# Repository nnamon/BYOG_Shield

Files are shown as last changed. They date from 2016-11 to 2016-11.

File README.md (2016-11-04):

# BYOG_Shield
Resources pertaining to the Build Your Own Arduino Shield workshop conducted by [AIS Cube](http://www.aiscube.com) and organised with [12Geeks](https://12geeks.com)

>Follow us on [Facebook](https://www.facebook.com/aiscube.sg)/[Instagram](https://www.instagram.com/aiscube.sg)/[Twitter](https://twitter.com/AIS_Cube) for upcoming public workshops & photos of those we conducted.

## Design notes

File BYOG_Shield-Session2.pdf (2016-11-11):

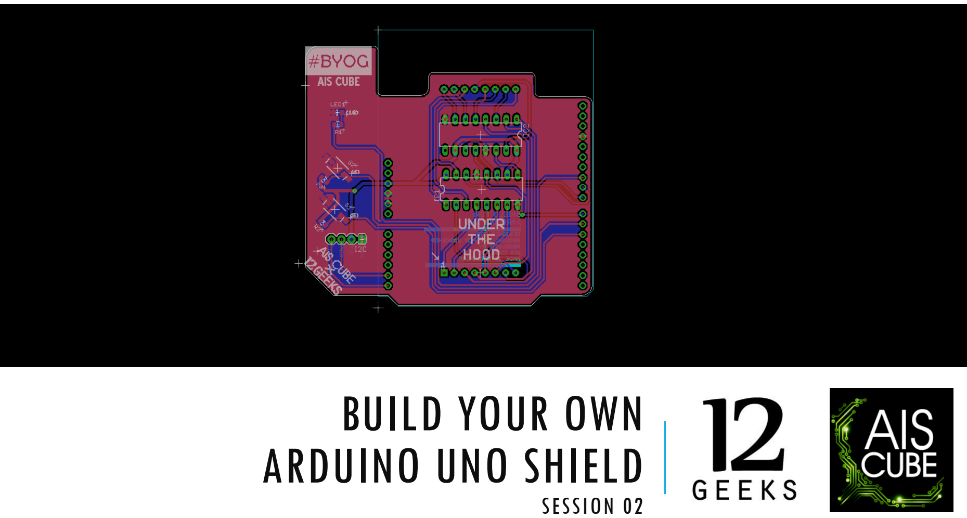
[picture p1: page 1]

# BUILD YOUR OWN ARDUINO UNO SHIELD

## SESSION 02

# LAST WEEK

Schematic
Drawing

Preparing
the board

Part
Placement

Preparing
to Route

Power
Lines

Signal
Lines

GND
Planes

Silkscreen
Items

## You learnt to:

- Breadboard & connect modules to the Arduino Uno
- Basic program to control the LEDs on the dot matrix
- Set up EAGLE directories
- Add components in EAGLE

# THIS WEEK

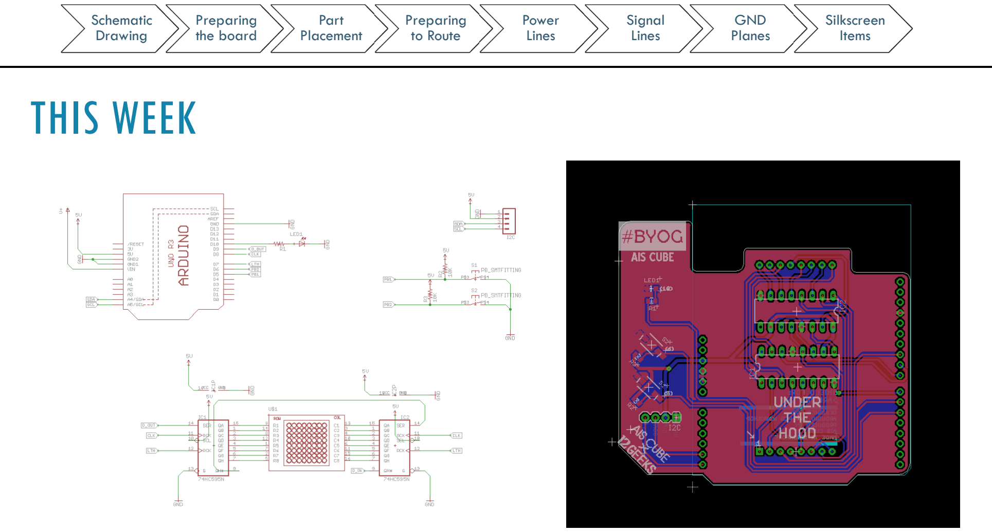
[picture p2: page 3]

Schematic
Drawing

Preparing
the board

Part
Placement

Preparing
to Route

Power
Lines

Signal
Lines

GND
Planes

Silkscreen
Items

# WAYPOINTS

- Board
Dimensions
- Change grid
units to mm
- Good parts
placement is
half the battle
won
- Change grid
units to 10 mil
- Setting up
route
parameters
- Eg. (Bend
Style, Width,
Via shape, via
drill size)
- Trace width
of 32 mil
- Route lines in
parallel on
bottom layer
- Trace width
of 16 mil
- Route lines on
top layer
- Polygons,
signals
and
ratsnest
- Logo
- Labels

# ADDING COMPONENTS

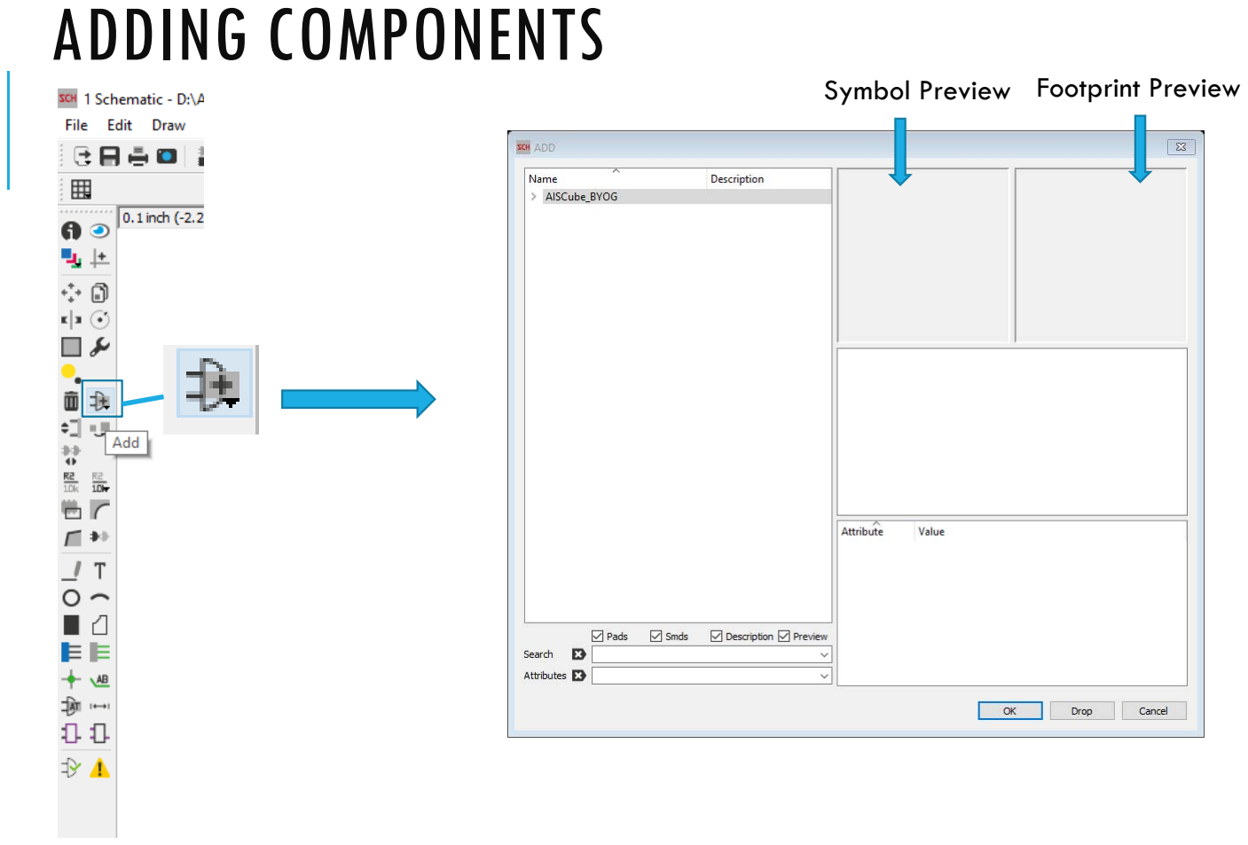
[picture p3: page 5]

Symbol Preview Footprint Preview

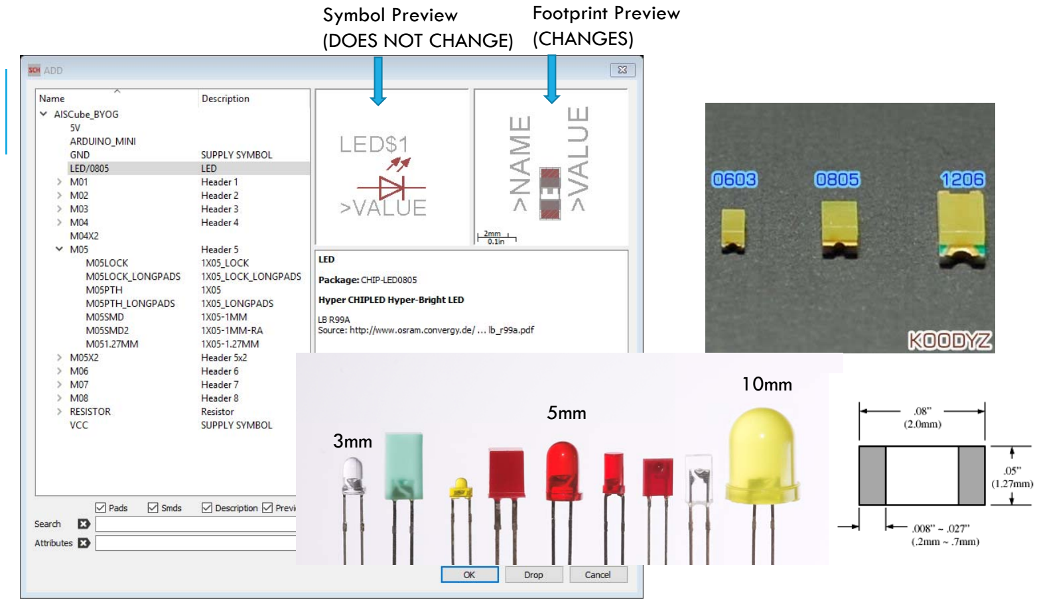
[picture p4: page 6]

Symbol Preview
(DOES NOT CHANGE)

Footprint Preview
(CHANGES)

3mm

5mm

10mm

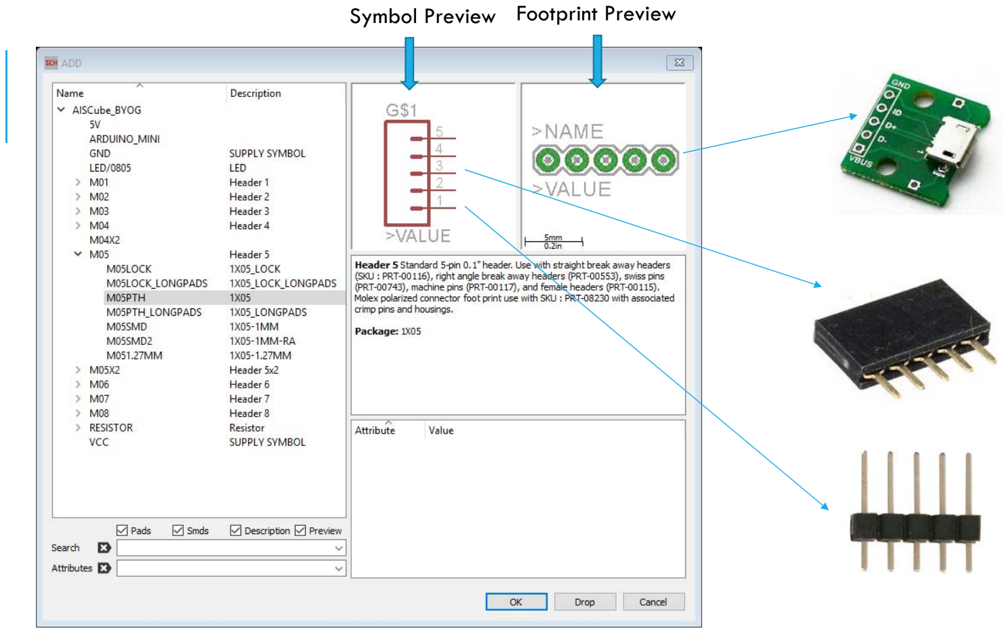
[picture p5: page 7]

Symbol Preview Footprint Preview

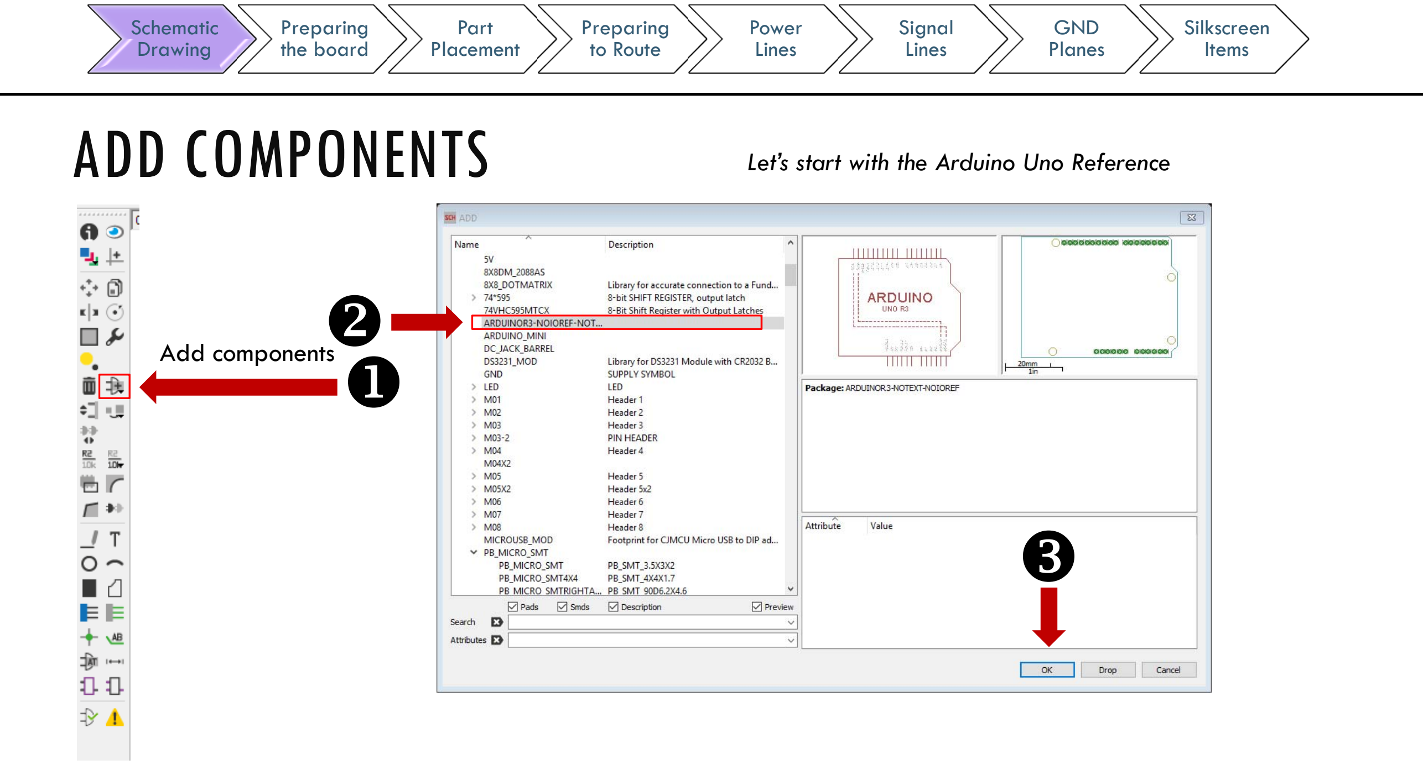
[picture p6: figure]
ADD COMPONENTS; Add components; Schematic Drawing; Preparing the board; Part Placement; Preparing to Route; Power Lines; Signal Lines; GND Planes; Silkscreen Items

Let’s start with the Arduino Uno Reference

# ADD POWER SYMBOLS

Add components

Schematic
Drawing

Preparing
the board

Part
Placement

Preparing
to Route

Power
Lines

Signal
Lines

GND
Planes

Silkscreen
Items

Add 5V and GND

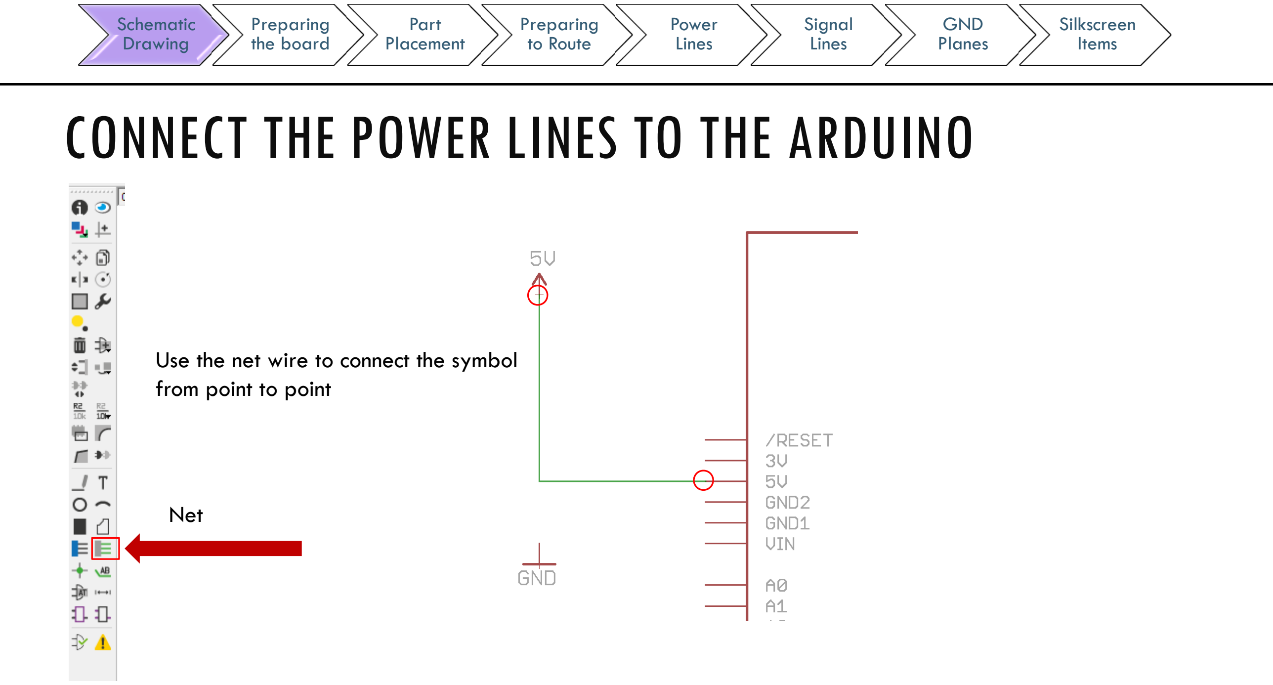
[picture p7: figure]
CONNECT THE POWER LINES TO THE ARDUINO; Net; Schematic Drawing; Preparing the board; Part Placement; Preparing to Route; Power Lines; Signal Lines; GND Planes; Silkscreen Items; Use the net wire to connect the symbol from point to point

# YOUR FIRST EAGLE CIRCUIT

Schematic
Drawing

Preparing
the board

Part
Placement

Preparing
to Route

Power
Lines

Signal
Lines

GND
Planes

Silkscreen
Items

# TRY DOING THIS BY YOURSELF

“Hello World” EAGLE style

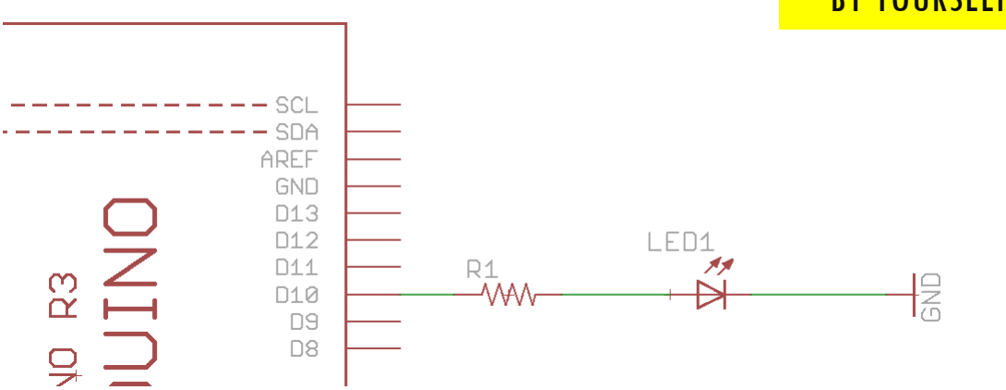
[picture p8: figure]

# UNDERSTANDING HOW .SCH & .BRD ARE CONNECTED

Schematic
Drawing

Preparing
the board

Part
Placement

Preparing
to Route

Power
Lines

Signal
Lines

GND
Planes

Silkscreen
Items

# EAGLE WALKTHROUGH

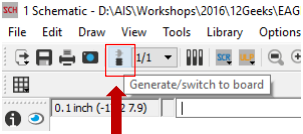
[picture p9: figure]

LIVE DEMO TIP :
Using move to auto-magically generate net wire connections.
Using copy to make copies of existing components (eg. GND) to add to the circuit. Net wire in .sch

→ air wire in .brd

# LET’S TRY THAT OUT WITH THE PUSH BUTTONS

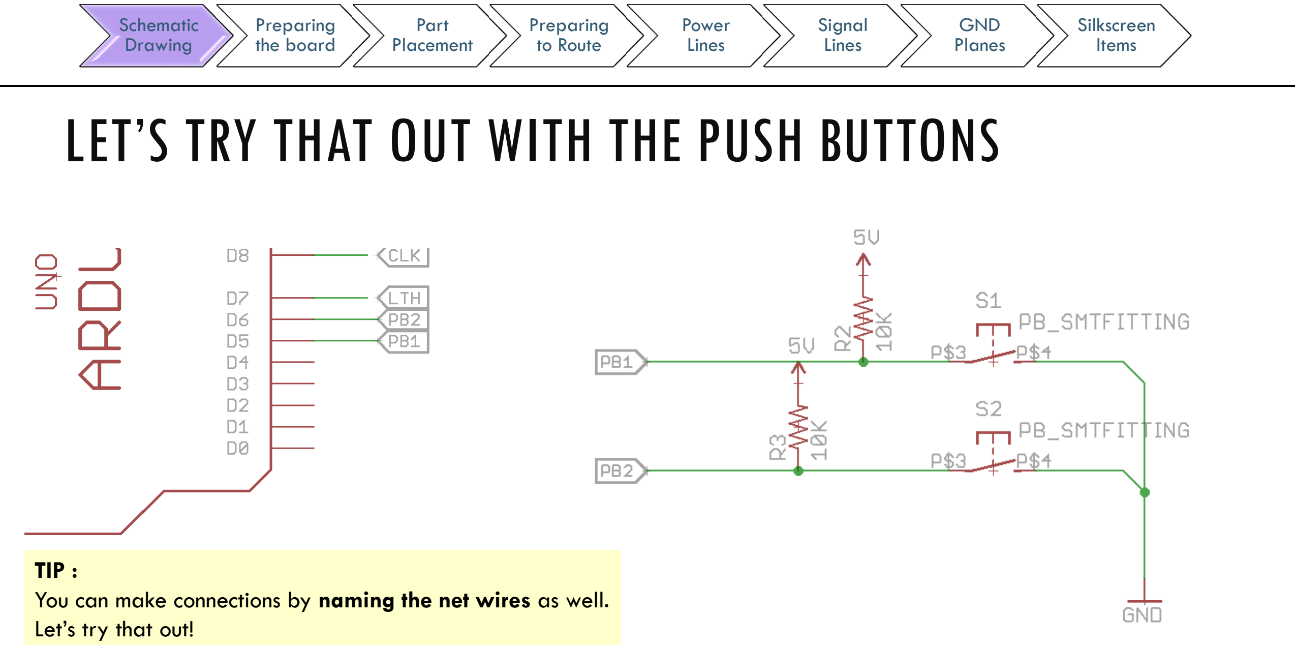
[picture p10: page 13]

Schematic
Drawing

Preparing
the board

Part
Placement

Preparing
to Route

Power
Lines

Signal
Lines

GND
Planes

Silkscreen
Items

TIP :
You can make connections by naming the net wires as well. Let’s try that out!

# NEW TIPS, AND HERE COMES THE MATRIX

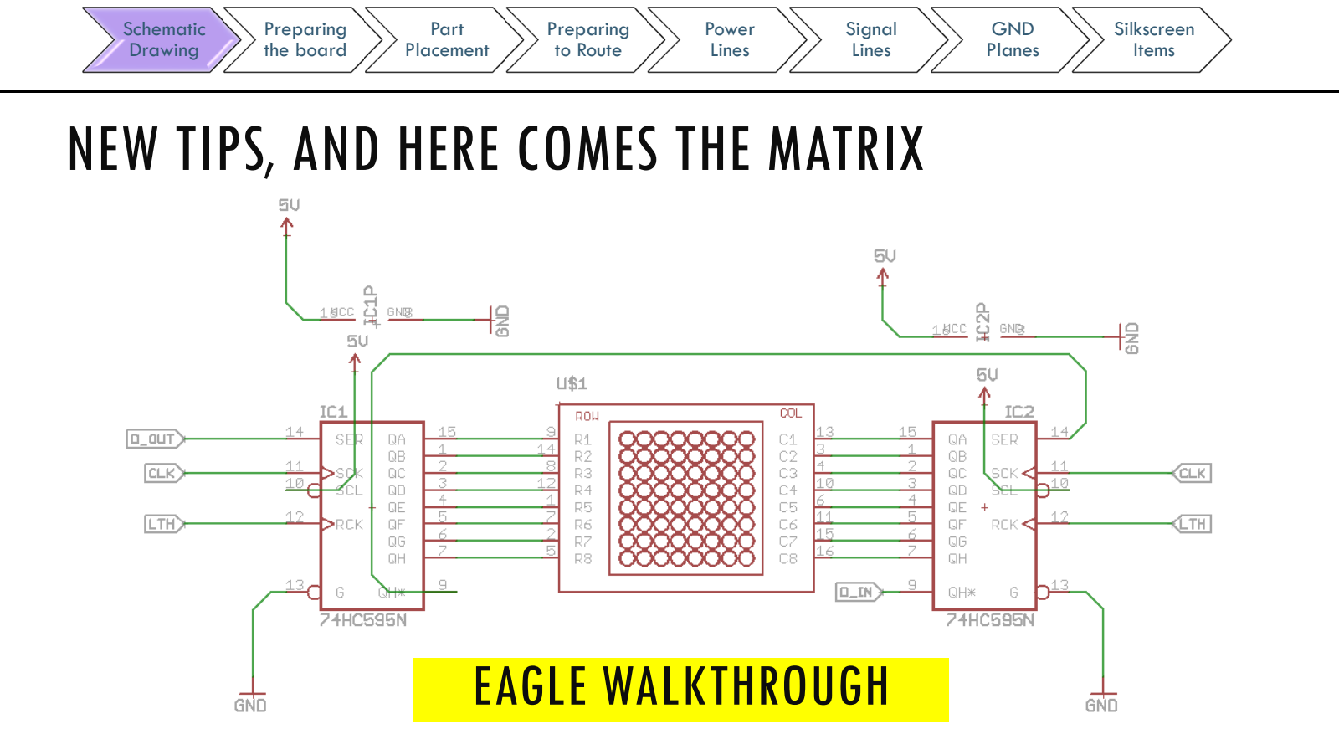
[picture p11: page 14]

Schematic
Drawing

Preparing
the board

Part
Placement

Preparing
to Route

Power
Lines

Signal
Lines

GND
Planes

Silkscreen
Items

# EAGLE WALKTHROUGH

# BY THIS TIME, YOUR ARDUINO SHOULD HAVE THE FOLLOWING PIN OUTS

Schematic
Drawing

Preparing
the board

Part
Placement

Preparing
to Route

Power
Lines

Signal
Lines

GND
Planes

Silkscreen
Items

# PANDEMIC PINDEMIC BREAKOUT

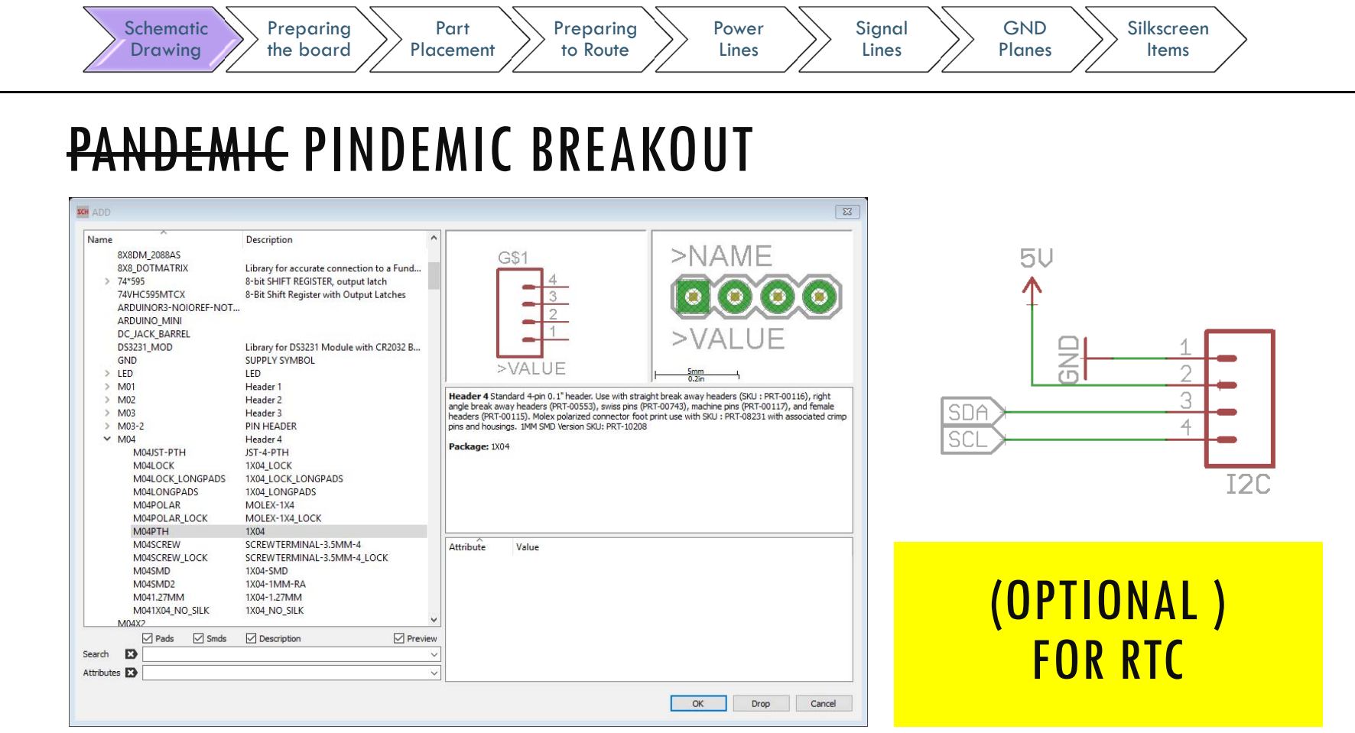
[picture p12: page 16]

Schematic
Drawing

Preparing
the board

Part
Placement

Preparing
to Route

Power
Lines

Signal
Lines

GND
Planes

Silkscreen
Items

# (OPTIONAL ) FOR RTC

# ERROR CHECKING (ERC)

Schematic
Drawing

Preparing
the board

Part
Placement

Preparing
to Route

Power
Lines

Signal
Lines

GND
Planes

Silkscreen
Items

### - Common Mistakes - Error Descriptions, what they mean, and how to solve it

ERC

ERC = Electrical Rule Check
This command is used to test schematics for electrical errors.

Schematic
Drawing

Preparing
the board

Part
Placement

Preparing
to Route

Power
Lines

Signal
Lines

GND
Planes

Silkscreen
Items

# GREAT JOB GETTING HERE

# LET’S TAKE A BREAK

# WAYPOINTS

- Board
Dimensions
- Change grid
units to mm
- Good parts
placement is
half the battle
won
- Change grid
units to 10 mil
- Setting up
route
parameters
- Eg. (Bend
Style, Width,
Via shape, via
drill size)
- Trace width
of 32 mil
- Route lines in
parallel on
bottom layer
- Trace width
of 16 mil
- Route lines on
top layer
- Polygons,
signals
and
ratsnest
- Logo
- Labels

Components situated
OUTSIDE of the board

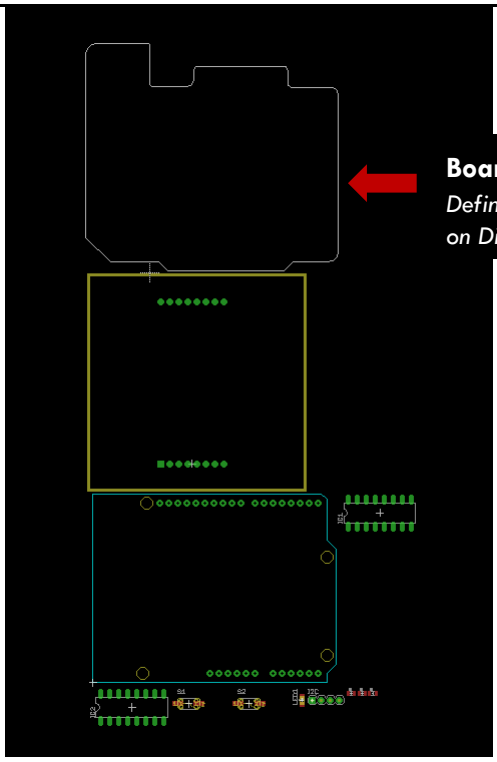
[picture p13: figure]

Board Dimension
Defined with Line of width 0 on Dimension Layer

Schematic
Drawing

Preparing
the board

Part
Placement

Preparing
to Route

Power
Lines

Signal
Lines

GND
Planes

Silkscreen
Items

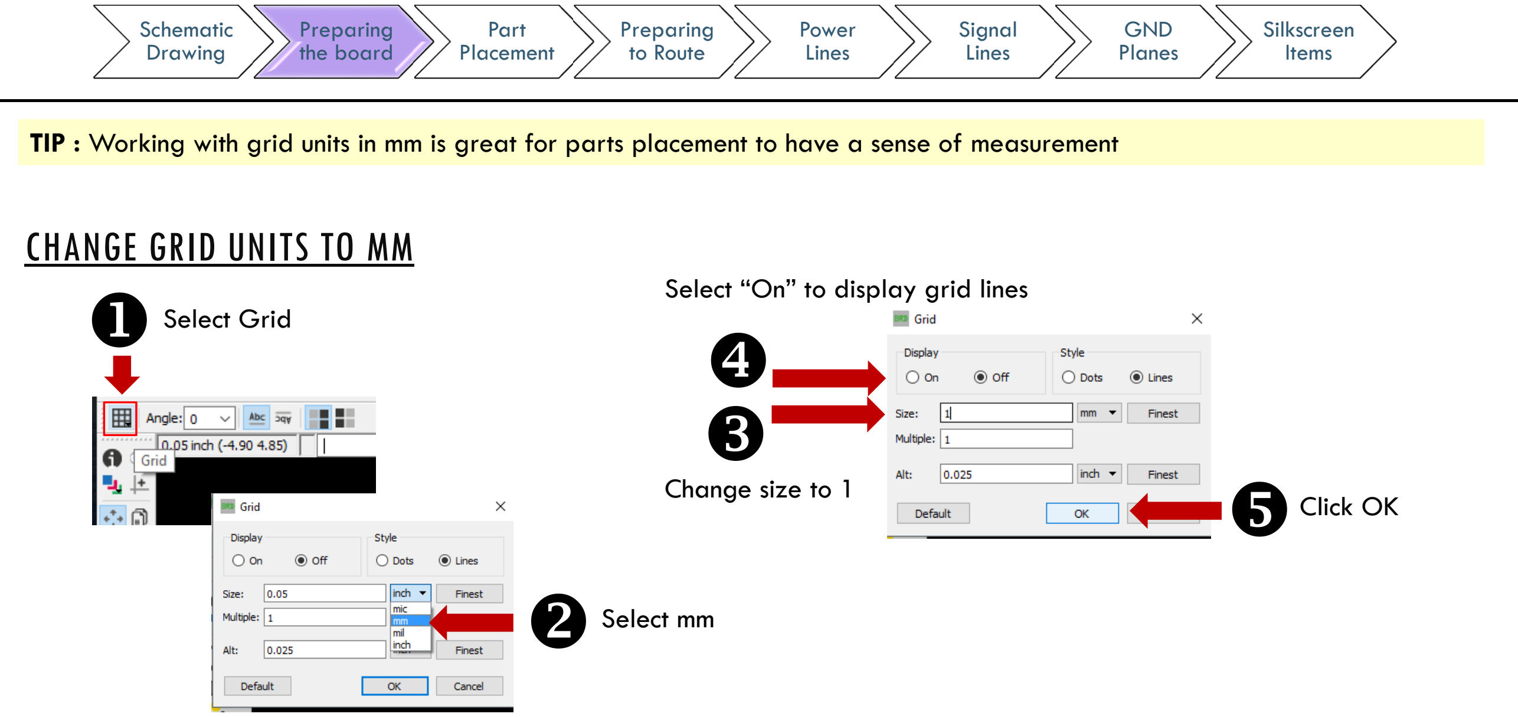
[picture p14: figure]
Select Grid; CHANGE GRID UNITS TO MM; Select mm; Change size to 1; Select “On” to display grid lines; Click OK; Schematic Drawing; Preparing the board; Part Placement; Preparing to Route; Power Lines; Signal Lines; GND Planes; Silkscreen Items

TIP : Working with grid units in mm is great for parts placement to have a sense of measurement

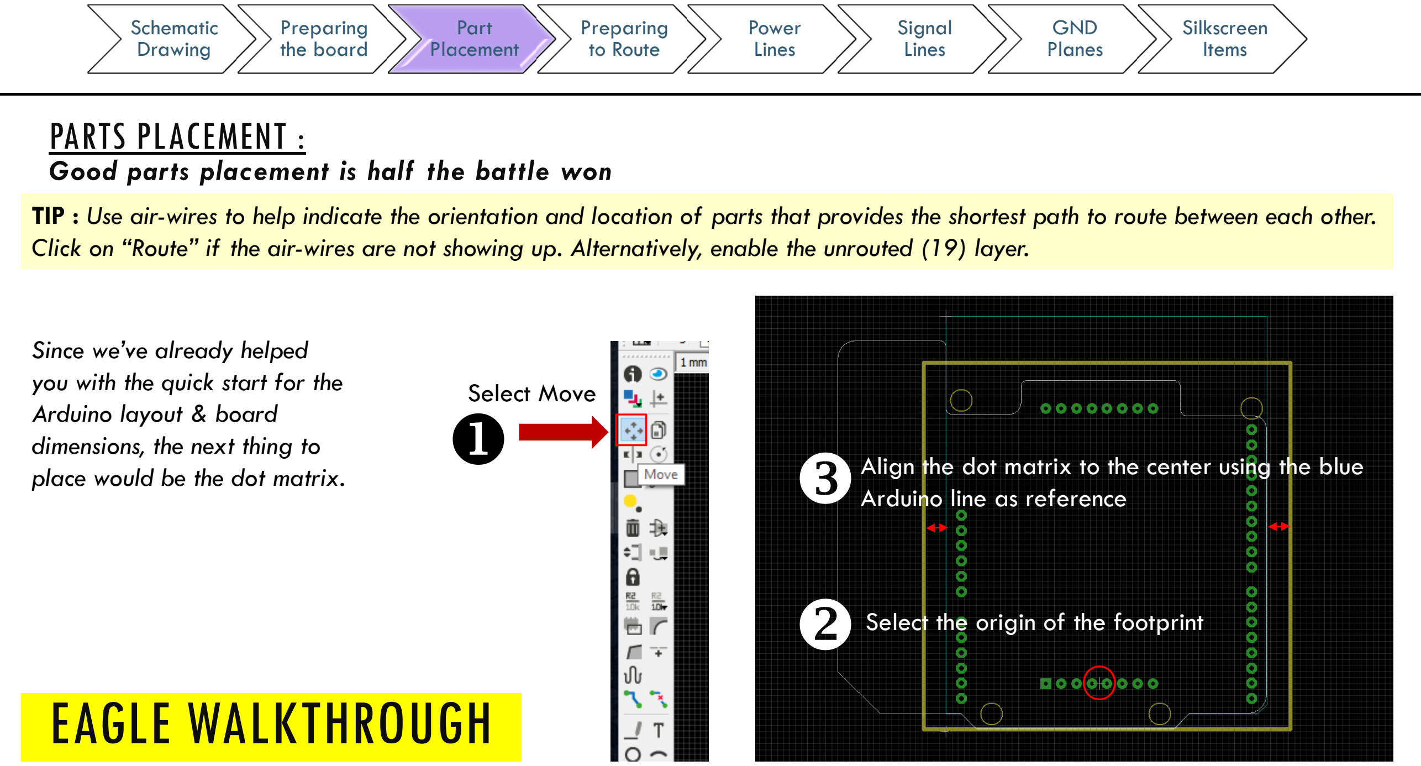
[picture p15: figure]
Select Move; PARTS PLACEMENT :; Since we’ve already helped you with the quick start for the Arduino layout & board dimensions, the next thing to place would be the dot matrix.; Schematic Drawing; Preparing the board; Part Placement; Preparing to Route; Power Lines; Signal Lines; GND Planes; Silkscreen Items; Select the origin of the footprint; EAGLE WALKTHROUGH

Good parts placement is half the battle won
TIP : Use air-wires to help indicate the orientation and location of parts that provides the shortest path to route between each other. Click on “Route” if the air-wires are not showing up. Alternatively, enable the unrouted (19) layer.

Align the dot matrix to the center using the blue Arduino line as reference

TIP : While deciding on where to place the parts, keep in mind that it should not block the connection to other components/ other components are not blocking it.

Eg. OK to place shift registers underneath the dot matrix module.
NOT OK to place the push buttons or LEDs underneath the dot matrix module.

Schematic
Drawing

Preparing
the board

Part
Placement

Preparing
to Route

Power
Lines

Signal
Lines

GND
Planes

Silkscreen
Items

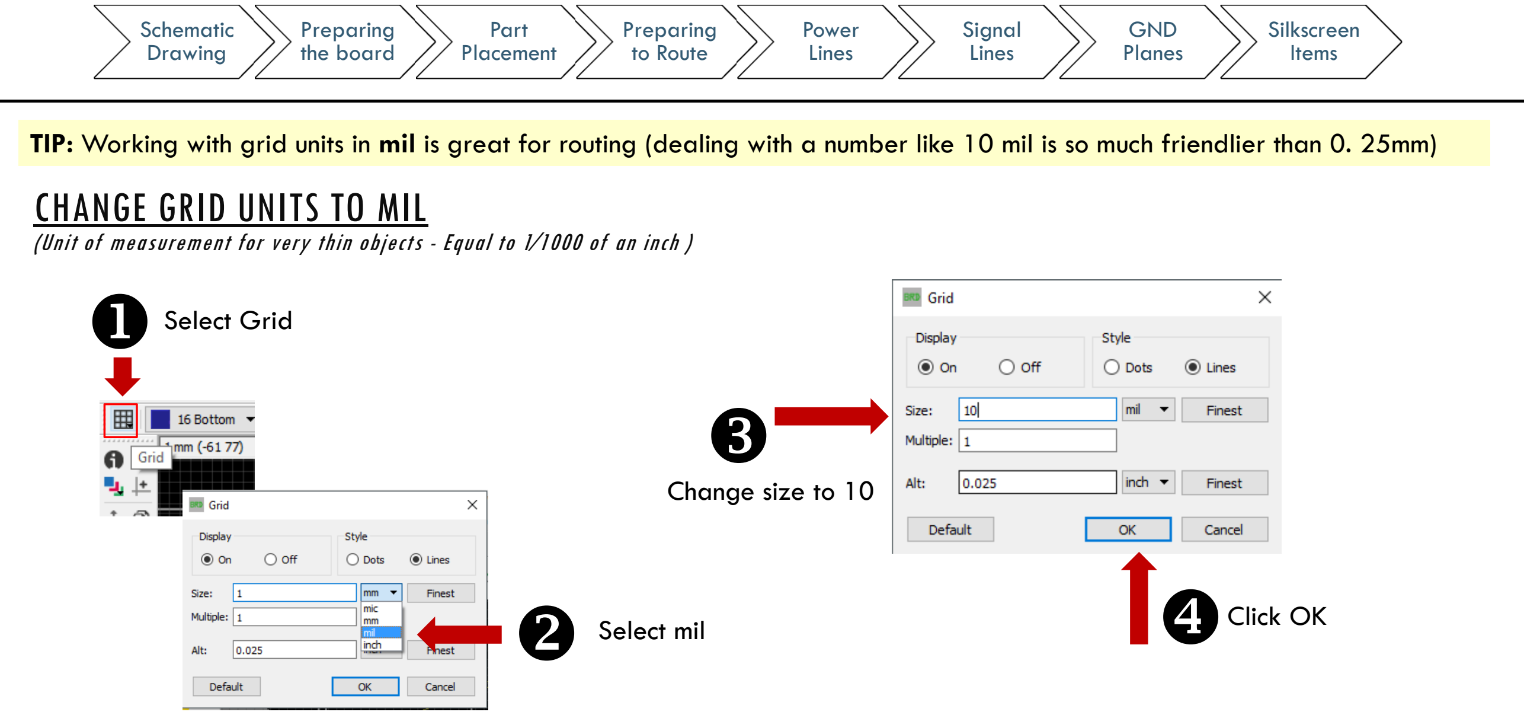
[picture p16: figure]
Select Grid; CHANGE GRID UNITS TO MIL; Change size to 10; Click OK; Select mil; Schematic Drawing; Preparing the board; Part Placement; Preparing to Route; Power Lines; Signal Lines; GND Planes; Silkscreen Items

(Unit of measurement for very thin objects - Equal to 1⁄1000 of an inch )

TIP: Working with grid units in mil is great for routing (dealing with a number like 10 mil is so much friendlier than 0. 25mm)

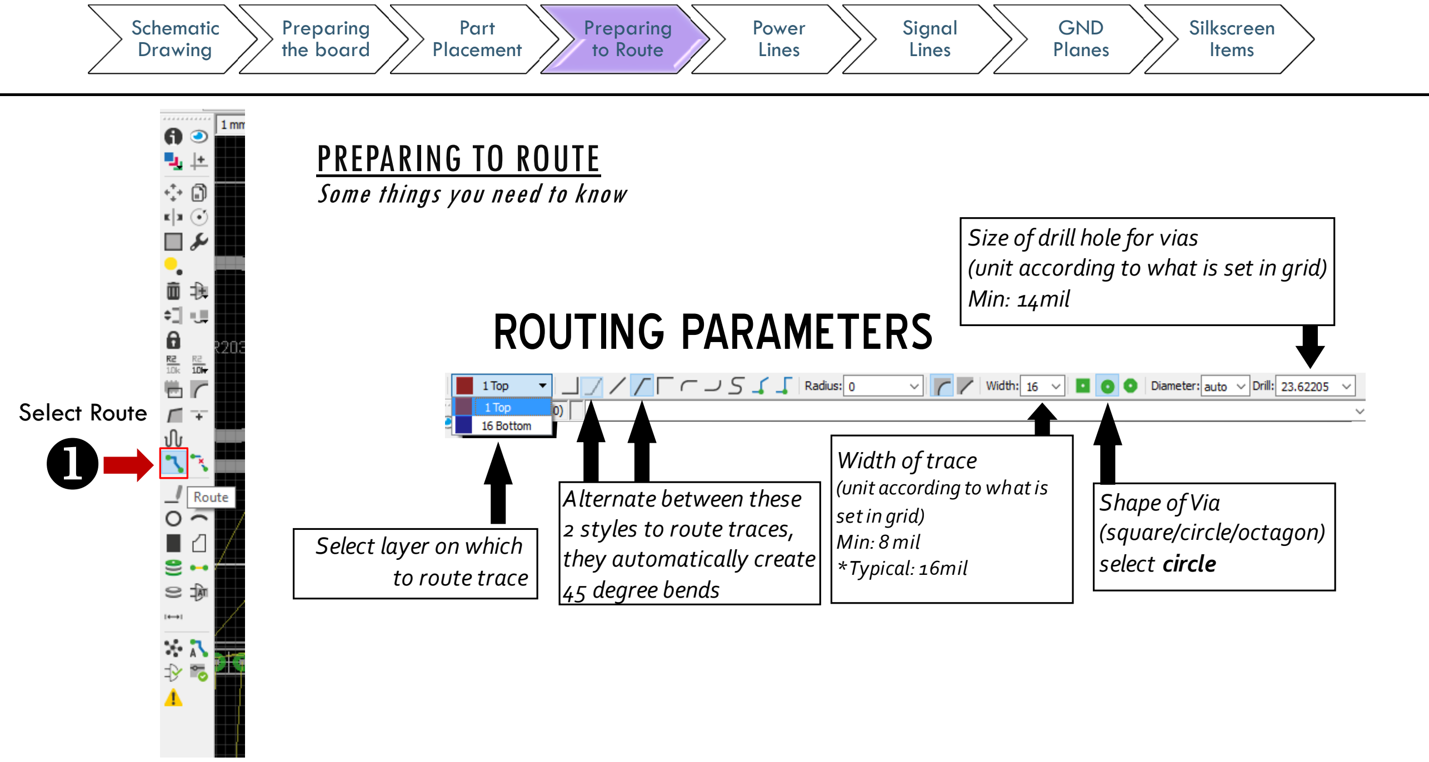
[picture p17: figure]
Select Route; PREPARING TO ROUTE Some things you need to know; ROUTING PARAMETERS; Select layer on which to route trace; Alternate between these 2 styles to route traces, they automatically create 45 degree bends; Width of trace (unit according to whatis setin grid) Min: 8 mil *Typical: 16mil; Shape ofVia (square/circle/octagon) select circle; Size of drill hole for vias (unit according to what is set in grid) Min: 14mil; Schematic Drawing; Preparing the board; Part Placement; Preparing to Route; Power Lines; Signal Lines; GND Planes; Silkscreen Items

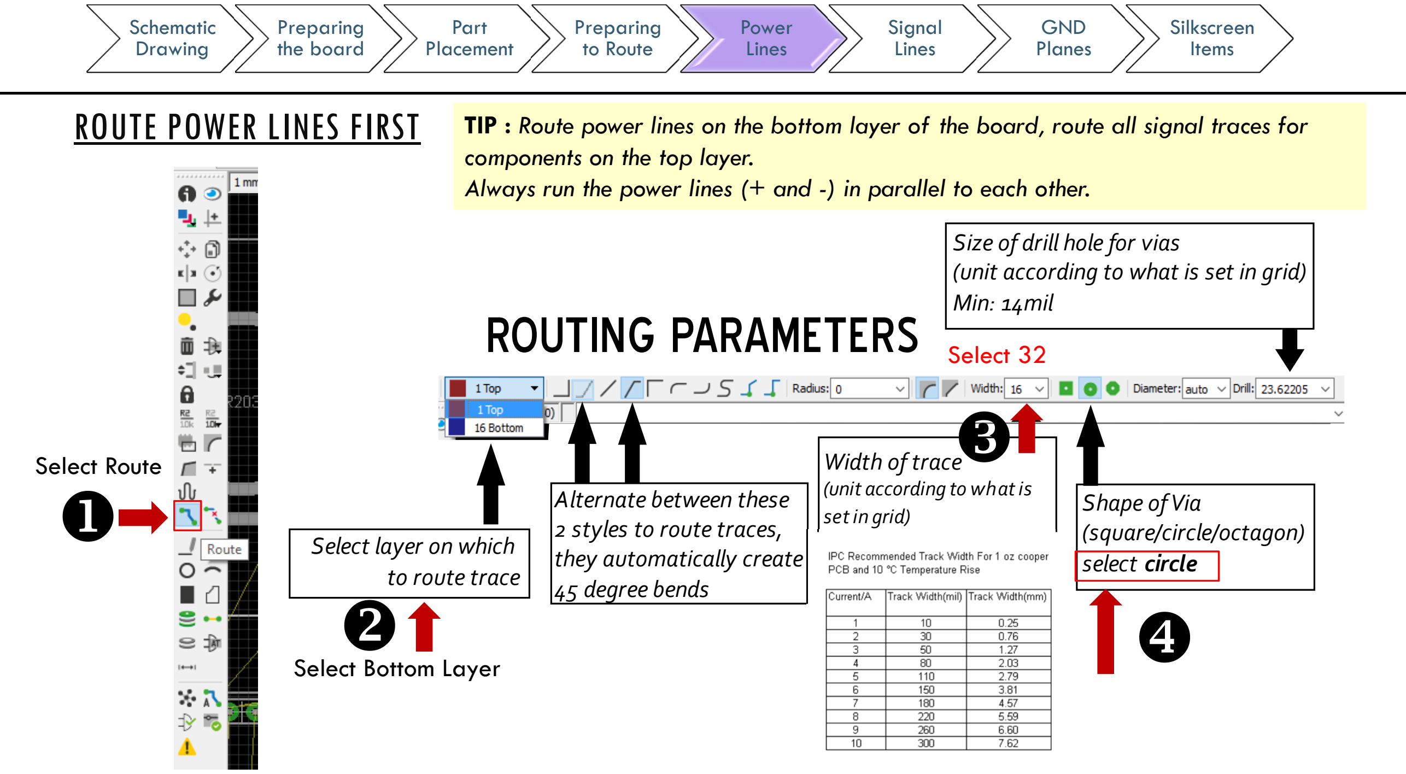
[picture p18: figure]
components on the top layer.; Select Route; ROUTING PARAMETERS; Select layer on which to route trace; Alternate between these 2 styles to route traces, they automatically create 45 degree bends; Width of trace (unit according to whatis setin grid) Min: 8 mil *Typical: 16mil; Shape ofVia (square/circle/octagon) select circle; Size of drill hole for vias (unit according to what is set in grid) Min: 14mil; Select Bottom Layer; Select 32; Schematic Drawing; Preparing the board; Part Placement; Preparing to Route; Power Lines; Signal Lines; GND Planes; Silkscreen Items

ROUTE POWER LINES FIRST TIP : Route power lines on the bottom layer of the board, route all signal traces for

Always run the power lines (+ and -) in parallel to each other.

ROUTE POWER LINES FIRST TIP : Route power lines on the bottom layer of the board, route all signal traces for components on the top layer.

Select air wire at GND of Arduino Board

Click to place a bend point

before continuing |

Click on centre of GND pin to complete trace route
Line should automatically disappear

Schematic
Drawing

Preparing
the board

Part
Placement

Preparing
to Route

Power
Lines

Signal
Lines

GND
Planes

Silkscreen
Items

ROUTE POWER LINES FIRST TIP : As much as possible, avoid daisy chaining the power lines from part-to-part.

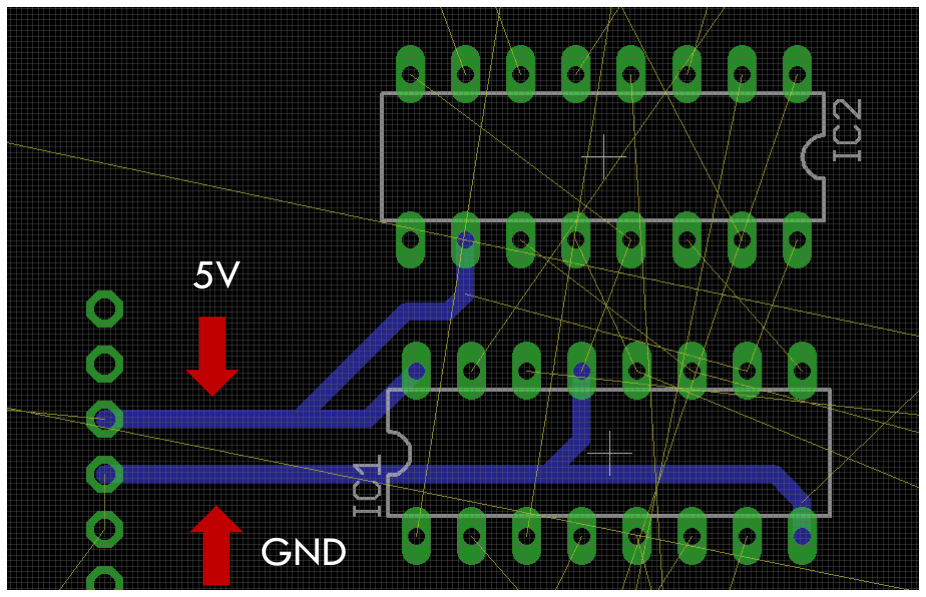
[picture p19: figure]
GND

“Always run the power lines (+ and -) in parallel to each other.” Repeat the steps the other 5V and GND lines.

Schematic
Drawing

Preparing
the board

Part
Placement

Preparing
to Route

Power
Lines

Signal
Lines

GND
Planes

Silkscreen
Items

TIP :
Use the grid lines to gauge minimum clearance between the traces. (That’s the reason why we use 10mil)

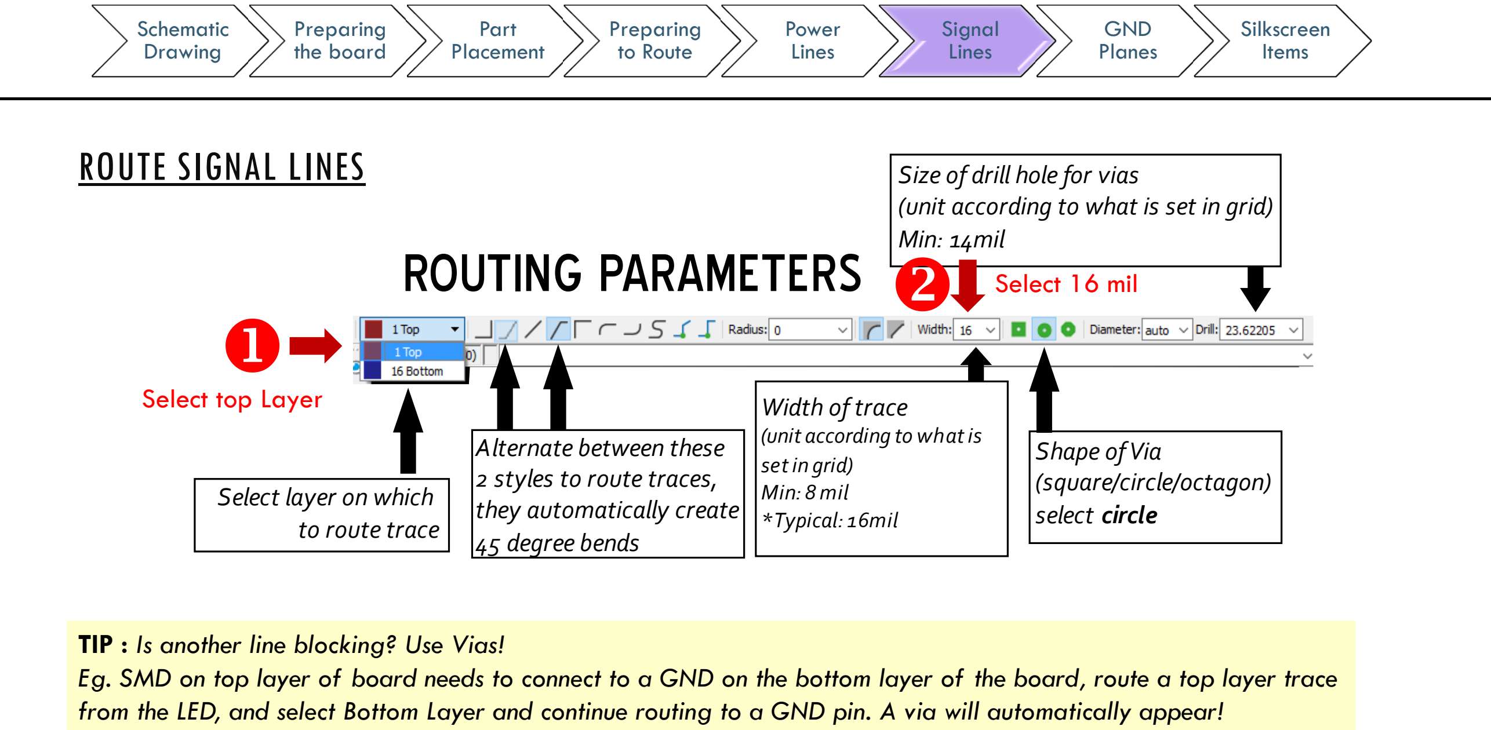
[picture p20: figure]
ROUTE SIGNAL LINES; ROUTING PARAMETERS; Select layer on which to route trace; Alternate between these 2 styles to route traces, they automatically create 45 degree bends; Width of trace (unit according to whatis setin grid) Min: 8 mil *Typical: 16mil; Shape ofVia (square/circle/octagon) select circle; Size of drill hole for vias (unit according to what is set in grid) Min: 14mil; Select top Layer; Select 16 mil; Schematic Drawing; Preparing the board; Part Placement; Preparing to Route; Power Lines; Signal Lines; GND Planes; Silkscreen Items

TIP : Is another line blocking? Use Vias!
Eg. SMD on top layer of board needs to connect to a GND on the bottom layer of the board, route a top layer trace from the LED, and select Bottom Layer and continue routing to a GND pin. A via will automatically appear!

## GROUND PLANES

Large area of copper connected to a circuit’s ground point.
- Serves as a return path for current from different components
- Reduces electrical noise, interference, crosstalk
- ..and other functions depending on the circuit

Select Polygon

1. Type GND
2. Hit Enter

Select Bottom Layer | Change to 10 mil

Live Demo
A. Click and follow the edges of the board to form a polygon
B. The polygon will turn into a dotted line when closed
C. Use show on the polygon to check that the signal is GND.
(Your GND traces should be highlighted together with the polygon, if it doesn’t, use “NAME” on the polygon to name it as GND. )
D. Do the same for the Top Layer
E. Click on Ratsnest to generate solid ground planes

Schematic
Drawing

Preparing
the board

Part
Placement

Preparing
to Route

Power
Lines

Signal
Lines

GND
Planes

Silkscreen
Items

Change to 16 mil

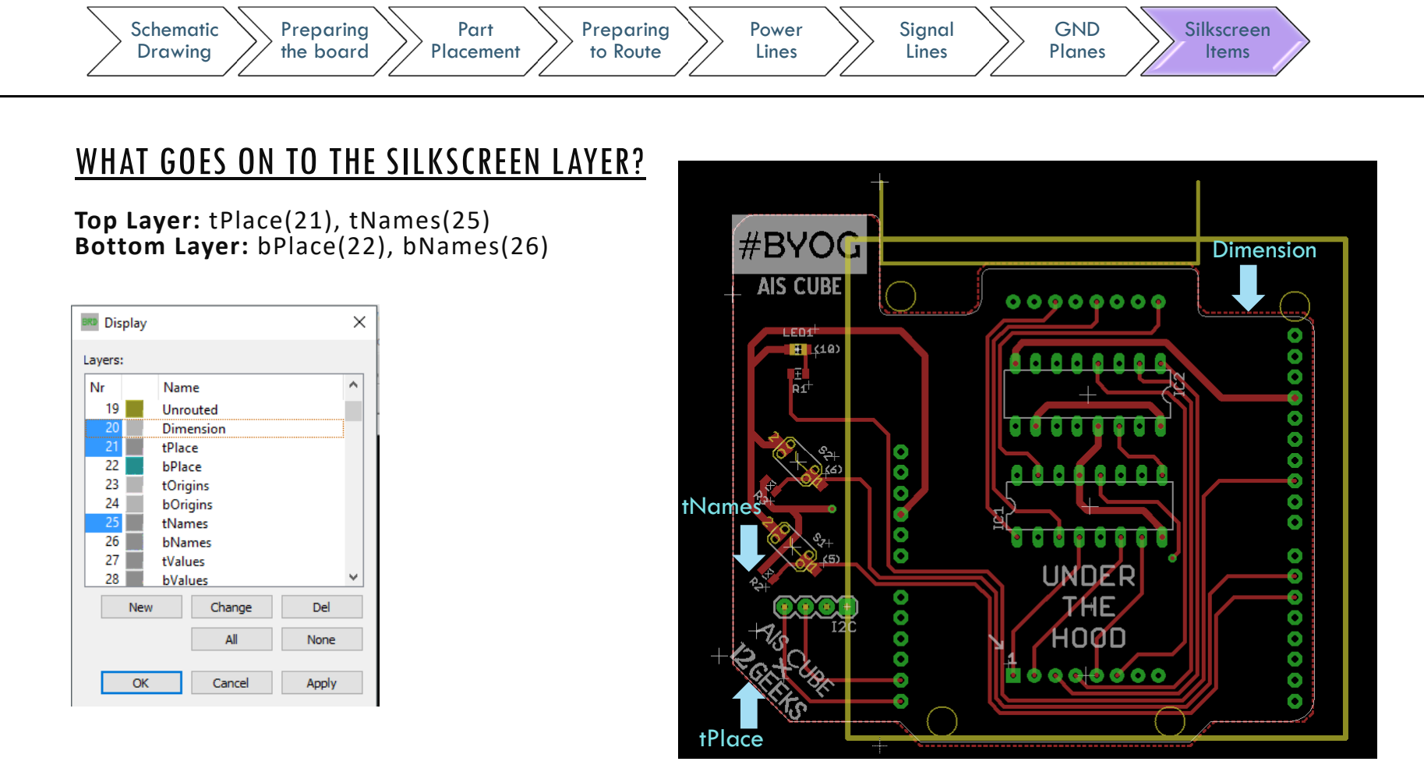
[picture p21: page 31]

## WHAT GOES ON TO THE SILKSCREEN LAYER?

Top Layer: tPlace(21), tNames(25)
Bottom Layer: bPlace(22), bNames(26) | Dimension

tPlace

tNames

Schematic
Drawing

Preparing
the board

Part
Placement

Preparing
to Route

Power
Lines

Signal
Lines

GND
Planes

Silkscreen
Items

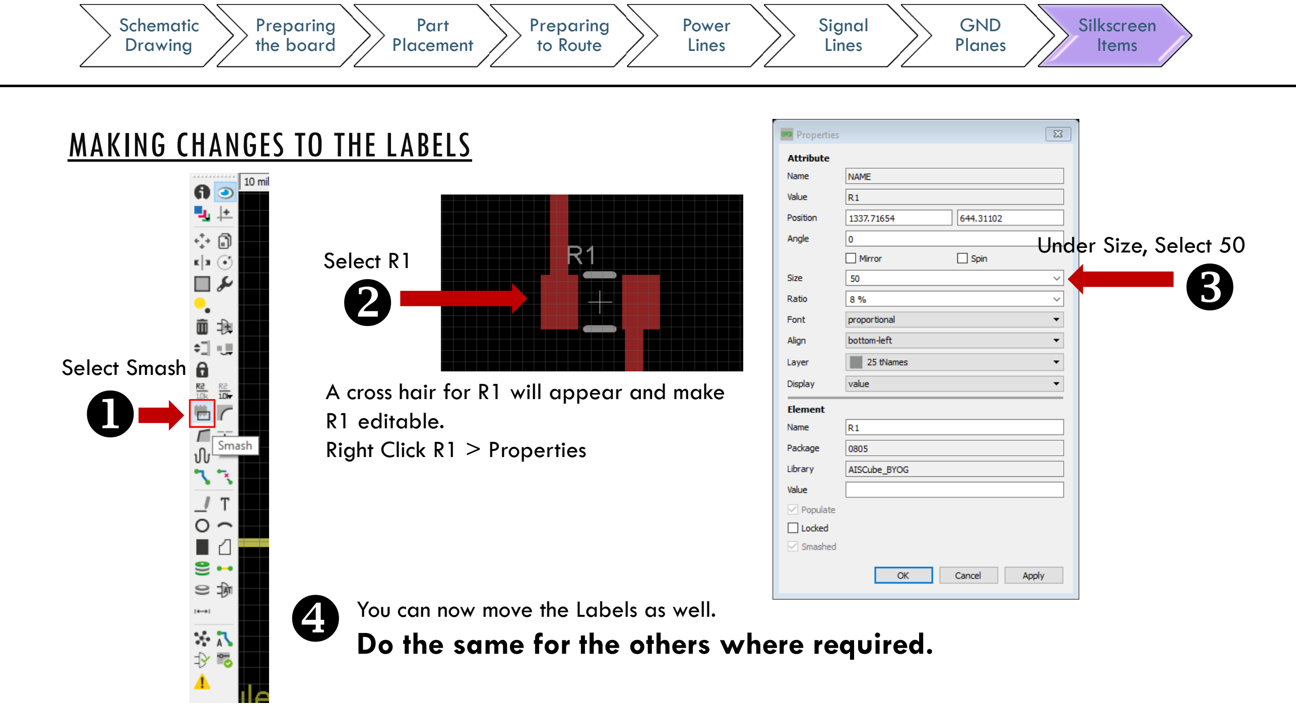
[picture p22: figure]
MAKING CHANGES TO THE LABELS; Select Smash; Select R1; R1 editable. Right Click R1 > Properties; You can now move the Labels as well.; Under Size, Select 50; Schematic Drawing; Preparing the board; Part Placement; Preparing to Route; Power Lines; Signal Lines; GND Planes; Silkscreen Items

A cross hair for R1 will appear and make

Do the same for the others where required.

## WRITING TEXT ON TO SILKSCREEN LAYER

Select tPlace for Top Layer
- Select bPlace for Bottom Layer

Play around with size, ratio and font till happy

(Remember: Ratio only works with Font: Vector!)

Select Text > Write text > Enter

NOTE:
You may choose to have just text, or just an image, or both on the silkscreen layer.
If you’re just placing text, follow the instructions here, and when you’re done, go straight to the last slide.
If you wish to place an image, continue till the last slide.

Schematic
Drawing

Preparing
the board

Part
Placement

Preparing
to Route

Power
Lines

Signal
Lines

GND
Planes

Silkscreen
Items

ALWAYS USE VECTOR FONT

## PREPARING YOUR IMAGE FOR SILKSCREEN (USING PAINT)

1. Make sure your image is in .bmp Format, Monochrome (1bit)
2. (If your image is already in Black & White but not in the above format, use Paint to Save As .bmp Monochrome)

WINDOWS USERS

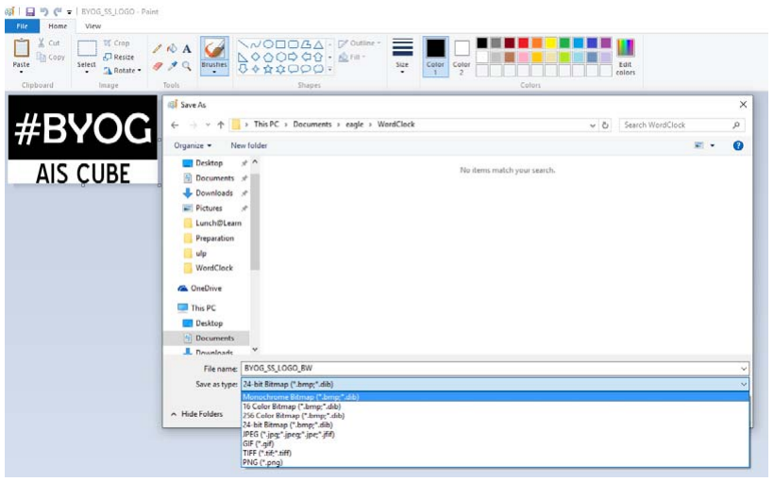
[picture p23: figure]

(If you have already done the conversion in PAINT, skip this slide)

Schematic
Drawing

Preparing
the board

Part
Placement

Preparing
to Route

Power
Lines

Signal
Lines

GND
Planes

Silkscreen
Items

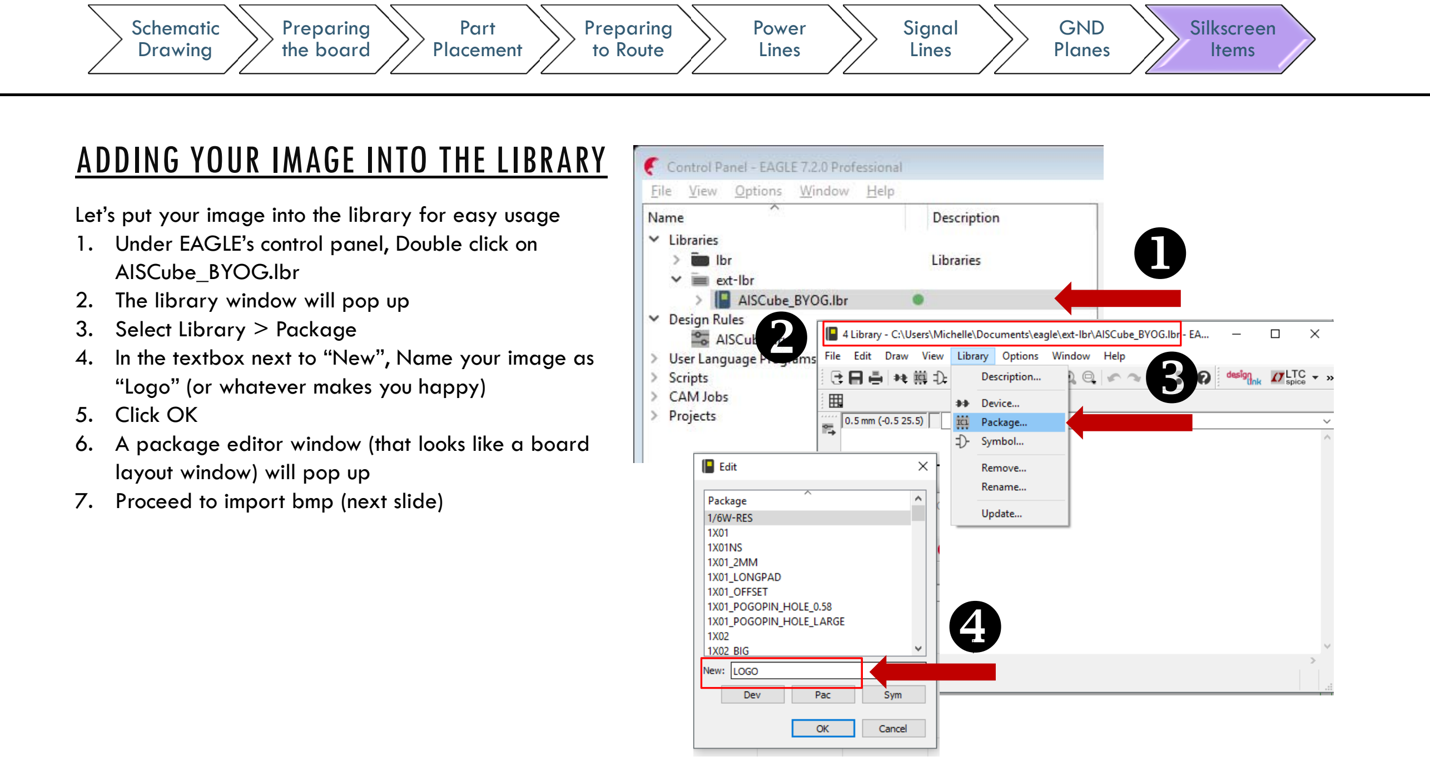
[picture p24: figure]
ADDING YOUR IMAGE INTO THE LIBRARY; AISCube_BYOG.lbr 2. The library window will pop up 3. Select Library > Package; “Logo” (or whatever makes you happy) 5. Click OK; layout window) will pop up 7. Proceed to import bmp (next slide); Schematic Drawing; Preparing the board; Part Placement; Preparing to Route; Power Lines; Signal Lines; GND Planes; Silkscreen Items

Let’s put your image into the library for easy usage
1. Under EAGLE’s control panel, Double click on
4. In the textbox next to “New”, Name your image as
6. A package editor window (that looks like a board

## IMPORT BMP

1. File > Run ULP
2. Select import-bmp.ulp
3. Select your image
4. Info Box > Click OK
5. Select Black > OK
6. Ensure your settings are as follows:
- Format: Scaled
- Unit: MM
- Scale Factor: 0.1
- Layer: 21 (tPlace)
7. OK > Run Script

### 8. Change the Grid to a value like 10mm to check sizing

9. If you would like to redo the image at a different size, Delete the entire group, and repeat from Step 1 while playing around with the scale factor till you’re happy with the sizing
10. Once you’re happy with the size, Save the library.
11. Go to EAGLE’s control panel
12. Update AISCube_BYOG.lbr (right click> update)
13. In your board design, Click on ADD > LOGO
14. Place logo onto board

Schematic
Drawing

Preparing
the board

Part
Placement

Preparing
to Route

Power
Lines

Signal
Lines

GND
Planes

Silkscreen
Items

# DONE!

## Please email your entire project folder to FAZLI@12GEEKS.COM By Sunday (13/11/2016) Night 2359 hours

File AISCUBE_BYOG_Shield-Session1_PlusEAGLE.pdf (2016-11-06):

# BUILD YOUR OWN ARDUINO UNO SHIELD

SESSION 01


# A LITTLE BACKGROUND INTRODUCTION

We’ve been around since 2002 PS: No, we’re not a start up PPS: No, I’m not a fresh grad

# BLOCK DIAGRAM

8*8 Dot Matrix LED Display; Power; Arduino; LED Indicator; Touch Modules

# SIMPLIFIED PROTOTYPING PROCESS


# WHAT’S A BREADBOARD?

What’s it used for
- Testing circuits
- Making non-permanent connections
- Easily add/remove components

# WHAT GOES INTO A BREADBOARD?


…And wires

Through-hole components

…and wires

# WHAT’S INSIDE A BREADBOARD?


Power Rails

Internals

Rows & Columns
for components

Power Rails

Doesn’t it remind
you of paper clips?


# LET’S GET STARTED

# LET’S TALK ABOUT POWER


VCC (+) GND (-)
Insert
Dual Row
5 Way Pin Header

# LET’S TALK ABOUT POWER

VCC (+) GND (-)

Power Rails

Rows & Columns
for components

Power Rails

# ANYBODY REMEMBER THIS?



# BASIC LED CIRCUIT


Through hole component
Looking for polarity
Resistors – 330 ohms
How the circuit works

# LET’S BUILD THAT LED CIRCUIT


PIN 10

# 8*8 DOT MATRIX LED DISPLAY

# 8*8 DOT MATRIX LED DISPLAY


# MODULE

8*8 dot matrix module
Under the hood – 2x 8bit Shift Registers (74HC595) Serial to Parallel


# CONNECTING THE DOT MATRIX MODULE


# POWER FIRST!

VCC

GND

# CONNECTING THE SERIAL LINES


D_OUT

CLK
LTH

PIN 8
PIN 7
PIN 9

# AND FOR THE GRAND FINALE

Adding the capacitive touch buttons to pins 5 & 6

# By yourself :p

# AND THAT’S IT!

Let’s program it.
For the next part, you will need to download the Arduino Program

HTTP://WWW.GITHUB.COM/AISCUBE/BYOG_Shield

Arduino Program Examples
SHIELD_8x8_ex1 – Display char at setup. SHIELD_8x8_ex2– Display 0 to 9. SHIELD_8x8_ex2b – Display A to Z. SHIELD_8x8_ex3 – Use PB1 to increase. SHIELD_8x8_ex3b – Use PB1 and PB2 to decrease. SHIELD_8x8_ex4 – animate Square.

# PROGRAMMING THE 8*8 DOT MATRIX


# INTRODUCTION TO EAGLE

# SO, YOU WANT TO MAKE YOUR OWN PCB

PCB = Printed Circuit Board
Tools of the trade:
- PCB CAD (Computer Aided Design) Design Software


Schematic (.sch) | Board Layout (.brd)


### Electronic Symbols

### “Footprint” of Electronic Parts

# DIVING RIGHT IN… WHY EAGLE?

▪Cross Platform – Windows/Mac/Linux
▪Free version is great for students/hobbyists (non-commercial)
- Limitations:
- 2 Layer Board
- Board Dimension: 10 * 8 cm
- Schematic : Max 2 Sheets
▪Great community support
- Loads of tutorials
▪Many open source hardware designers use EAGLE
▪Open Source Libraries – Need a part footprint? It’s probably already available somewhere out there.
- Eagle Community
- Sparkfun
- Adafruit
- Element14
- (and a lot more)

# SETTING UP EAGLE

We’ve provided some libraries and files that you will find useful in this workshop (and hopefully beyond.) We’ll need to let EAGLE know we have these files.
Look for the folder “eagle” inside the contents of the folder you downloaded from github.
Copy the folder into “Documents” so that it looks like this in file explorer. (or equivalent in MAC/Linux)

STEP 1; In the Control Panel of EAGLE: Go to Options > Directories; STEP 2; For Windows Users, Follow the screenshot below.; MAC (append using ‘:’); :/Users/yourComputerName/Documents/eagle/ext-lbr

Make the following changes for Libraries, Design Rules & CAM Jobs

# GO TO EAGLE’S CONTROL PANEL

## Expand ext-lbr


Click on the grey dot to enable use of the libraries

# LET’S CREATE A NEW PROJECT

Expand Projects
Right Click on eagle > New Project

NAME IT WHAT EVER YOU WANT.

Name it whatever you want

CREATE NEW SCHEMATIC; Right Click on your project; New > Schematic

# WELCOME TO EAGLE


# WELCOME TO EAGLE

WORKSPACE

# WELCOME TO EAGLE

ORIGIN (Serves as a reference point)

# LET’S SAVE THE SCHEMATIC

Any of these methods
FILE > SAVE
Save icon
Ctrl + S

# ADDING COMPONENTS


Symbol Preview Footprint Preview

Symbol Preview
(DOES NOT CHANGE)

Footprint Preview
(CHANGES)

3mm

5mm

10mm


Symbol Preview Footprint Preview

# HOMEWORK

Logo/Image for Silkscreen

Remember!
Bring your mouse! And your laptop charger / a fully charged laptop!

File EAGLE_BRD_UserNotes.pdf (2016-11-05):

Move MIRROR GROUP paste Delete pinswap LOCK name smash; Layer Settings; COPY ROTATE (ON origin) CHANGE; add element replace; value miter; MARK; Usually used with “group” to change properties of selected components in one shot (eg. “change” > select on change desired > “group” > select group of items > right click > change: group; Left click (hold and drag) to select an area. Left click and release to form multiple points for a polygon. (right click closes polygon); Positions item on top/ bottom layer; Name Nets & Components; Right click while moving to rotate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

# split MEANDER ROUTE draw line circle rectangle via hole

# Dimension

# INFO

# optimize

# SHOW

Opens properties of selected item Great for obtaining position of parts for alignment

Highlights selected item on schematic & board

RIP UP text arc polygon dimension attribute; autoroute; Drc (Design rule CHeck); ROUTING PARAMETERS; Select layer on which to route trace; Alternate between these 2 styles to route traces, they automatically create 45 degree bends; Width of trace (unit according to what is set in grid) Min: 8 mil *Typical: 16mil Power lines: 2x of signal lines (eg. 16x2 = 32mil); Shape of Via (square/circle/octagon) select circle; Size of drill hole for vias (unit according to what is set in grid) Min: 14mil; ABOUT TRACE WIDTHS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

Add Text (eg. Labels on silkscreen layer)

Draw symbols using these to indicate polarity/ part dimensions on tDocu/bDocu layers or silkscreen layers (eg. tPlace/bPlace)

# EAGLE BOARD Layout

# ratsnest erc error list

*Power lines: At least 2x of signal lines (eg. 16x2 = 32mil) *These numbers are good for most hobby projects. Always measure your total current consumption and plan

Selecting air-wire removes the entire trace

Use smash to move and edit the text of parts eg. Adjusting the font size/thickness and location

Route air-wire connections

Place a hole in the board
(eg. Mounting holes)

Used to create a solid GND plane after using polygon

## Command Buttons

design rules with reference to Fabrication house

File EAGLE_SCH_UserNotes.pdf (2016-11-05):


# Move MIRROR GROUP paste Delete pinswap gateswap name smash split


# draw line draw circle draw rect bus junction

# attribute module

# erc

# INFO Layer Settings COPY ROTATE (ON origin) CHANGE

# add Components replace

# value miter invoke text draw arc polygon net label dimension port

# errors

# SHOW MARK

Usually used with “group” to change properties of selected components in one shot (eg. “change” > select on change desired > “group” > select group of items > right click > change: group Left click (hold and drag) to select an area. Left click and release to form multiple points for a polygon. (right click closes polygon)

Flip components horizontally

Opens properties of selected item Right click > properties on item does the same

Name Nets & Components

Highlights selected item on schematic & board

Right click while moving to rotate

Draw net wire connections

Label Nets (options available)

Style: Plain/Arrow | Size | Thickness of Font Only applicable for vector font.

Add Text (eg. Writing notes on Info Layer)

Specify values of components
(eg. Resistor/Capacitor/Inductor, LED colour etc)

Generates warnings/errors detected

Mostly used in drawing symbols for new parts to add to library or for adding notes as
documentation in schematic

# EAGLE Schematics

# User Notes & Tips

Produced by AIS Cube

*Commonly used actions
**Seldom used actions

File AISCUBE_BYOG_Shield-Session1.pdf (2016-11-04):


# BUILD YOUR OWN ARDUINO UNO SHIELD

SESSION 01


# A LITTLE BACKGROUND INTRODUCTION

We’ve been around since 2002 PS: No, we’re not a start up PPS: No, I’m not a fresh grad

# BLOCK DIAGRAM

8*8 Dot Matrix LED Display; Power; Arduino; LED Indicator; Touch Modules

# SIMPLIFIED PROTOTYPING PROCESS



# WHAT’S A BREADBOARD?

What’s it used for
- Testing circuits
- Making non-permanent connections
- Easily add/remove components

# WHAT GOES INTO A BREADBOARD?


…And wires

Through-hole components

…and wires

# WHAT’S INSIDE A BREADBOARD?


Power Rails

Internals

Rows & Columns
for components

Power Rails

Doesn’t it remind
you of paper clips?


# LET’S GET STARTED


# LET’S TALK ABOUT POWER


VCC (+) GND (-)
Insert
Dual Row
5 Way Pin Header

# LET’S TALK ABOUT POWER


VCC (+) GND (-)

Power Rails

Rows & Columns
for components

Power Rails

# ANYBODY REMEMBER THIS?



# BASIC LED CIRCUIT


Through hole component
Looking for polarity
Resistors – 330 ohms
How the circuit works

# LET’S BUILD THAT LED CIRCUIT


PIN 10

# 8*8 DOT MATRIX LED DISPLAY


# 8*8 DOT MATRIX LED DISPLAY


# MODULE

8*8 dot matrix module
Under the hood – 2x 8bit Shift Registers (74HC595) Serial to Parallel


# CONNECTING THE DOT MATRIX MODULE


# POWER FIRST!

VCC

GND

# CONNECTING THE SERIAL LINES


D_OUT

CLK
LTH

PIN 8
PIN 7
PIN 9

# AND FOR THE GRAND FINALE

Adding the capacitive touch buttons to pins 5 & 6

# By yourself :p

# AND THAT’S IT!

Let’s program it.
For the next part, you will need to download the Arduino Program

HTTP://WWW.GITHUB.COM/AISCUBE/BYOG_Shield

Arduino Program Examples
SHIELD_8x8_ex1 – Display char at setup. SHIELD_8x8_ex2– Display 0 to 9. SHIELD_8x8_ex2b – Display A to Z. SHIELD_8x8_ex3 – Use PB1 to increase. SHIELD_8x8_ex3b – Use PB1 and PB2 to decrease. SHIELD_8x8_ex4 – animate Square.

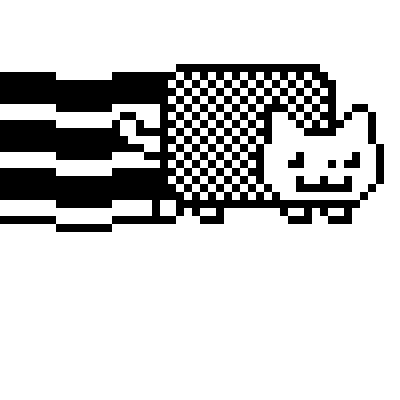
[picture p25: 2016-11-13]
eagle/nyan_cat.bmp

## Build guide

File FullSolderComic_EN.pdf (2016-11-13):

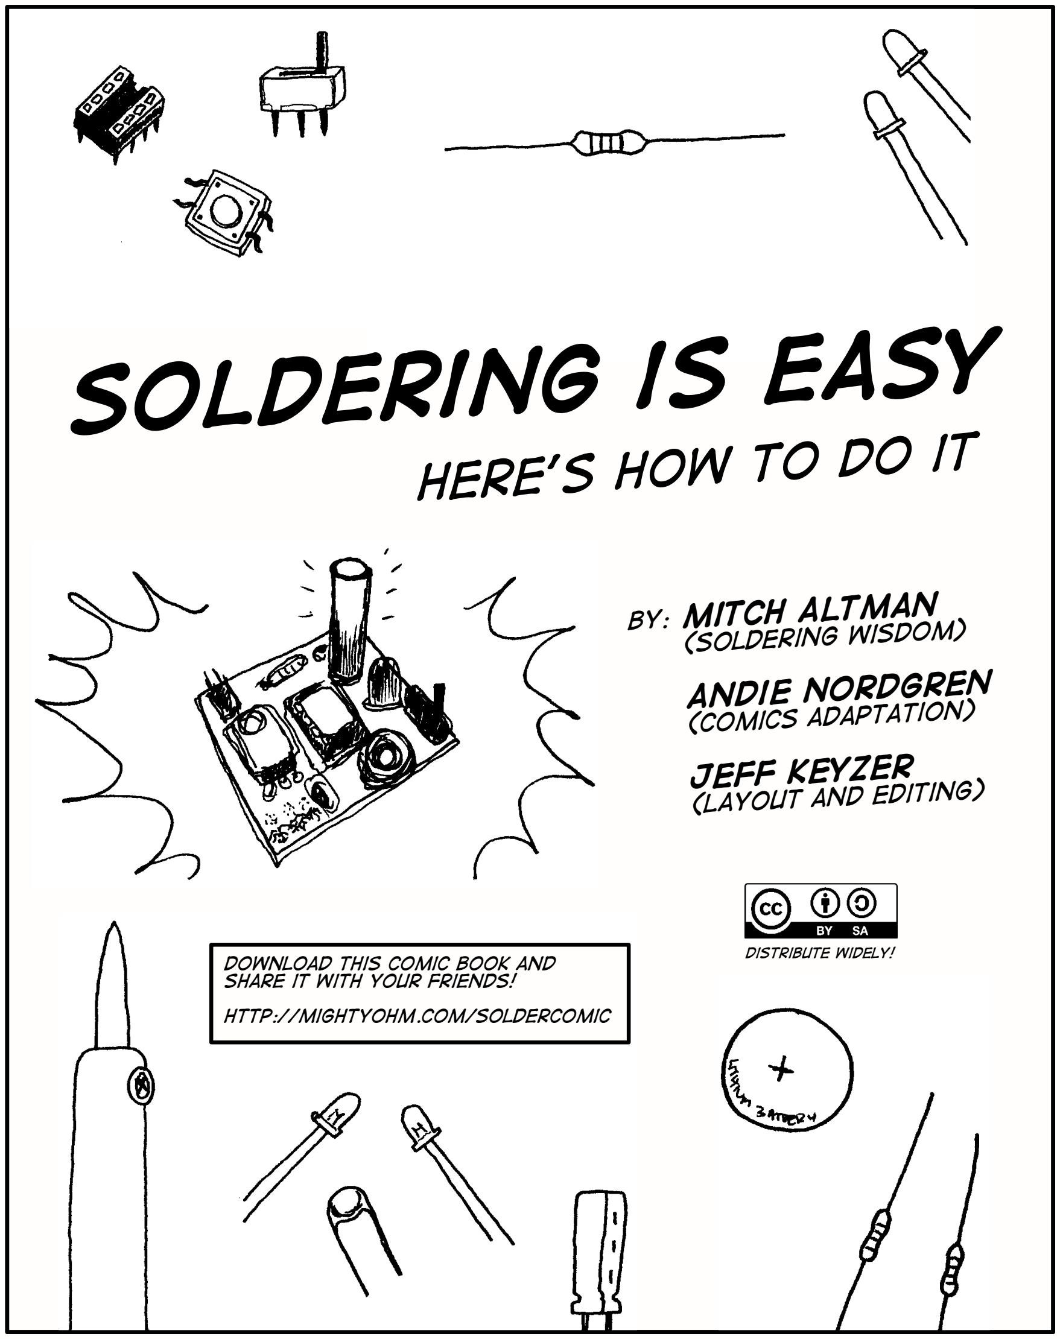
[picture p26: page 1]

# Soldering is easy

# here's how to do it

# by: Mitch Altman

# (soldering wisdom)

# Andie Nordgren

# (Comics adaptation)

# Jeff Keyzer

# (Layout and editing)

## Distribute widely! Download this comic book and share it with your friends!

## http://mightyohm.com/soldercomic

Soldering is a really useful skill.

# It is also way easy!

### REally, it is!

You’ll see.

### Soldering is also lots of fun!

If you know how to solder, you can make just

## about anything with electronics, which is

just too cool!
There are many ways to make good solder connections.
I’m going to explain how I do it.

# Let's get started!

This is a soldering iron.

Its tip gets hot enough to melt solder, which is metal.
That's about 200 degrees Celsius!

### Safety tip #1 (of 3): If you touch the tip, you will

### let go very quickly!

This is solder.
It is made of metal, Usually tin and lead.

the elements

### Sn and Pb

## It is actually hollow and filled with rosin

(similar to the stuff used to make bows for violins

sticky).

### When the solder heats up, the rosin melts almost immediately

The Metal
follows
shortly
thereafter

The ROSIN flows around what you want to solder, cleans the metal, and helps make a good solder connection.

We use the soldering iron to melt the solder and make electrical connections.

### The best solder for electronics has

rosin core and is 60% tin, 40% lead.
also known
as flux

There are other types, for instance lead-free solder, but it has toxic chemicals in its core, and it is not quite as easy to use as solder with lead. It also corrodes soldering iron tips quickly. If you can only get lead-free solder where you live, it’s OK, but please don’t breathe in the nasty smoke.

# Safety tip #2 (of 3):

## Lead is poisonous. It gets

on your skin when you hold the

## solder, so wash your hands after soldering!

If you don’t wash your hands after soldering, the lead may get in your body, where it gets stored in your brain for your entire life. if enough collects there then you go insane, and you lose all of your friends. So - wash your hands after soldering, and keep your friends!

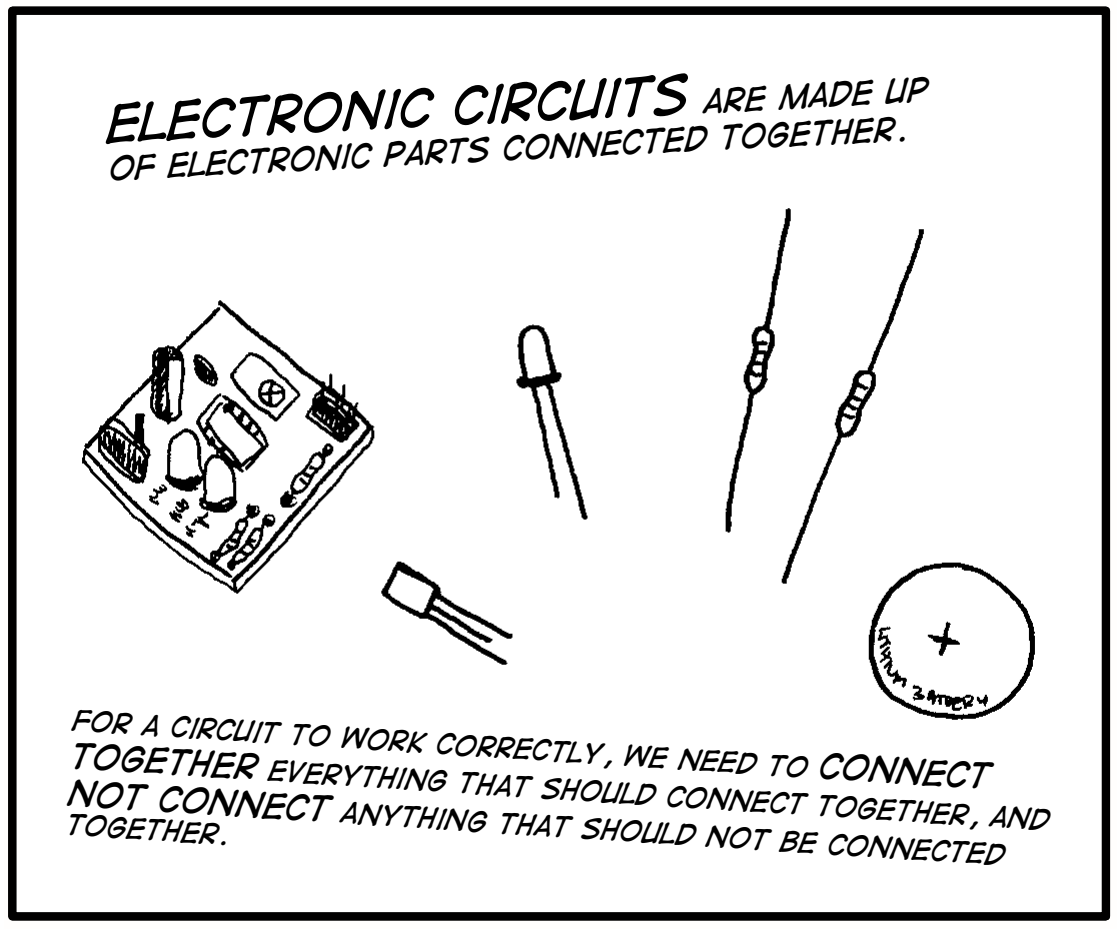
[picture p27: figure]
Electronic circuits are made up of electronic parts connected together.; connect; together.

For a circuit to work correctly, we need to
together everything that should connect together, and not connect anything that should not be connected

There are many ways to connect electronic parts together, but perhaps the easiest way is with a

# Printed Circuit Board

PCB or
just

### "THE

### Board"

The PCB makes
it easy because
it has

# pads for

each part.

If you look carefully at the PCB, you will see lines connecting pads together with other pads – these lines are called traces.

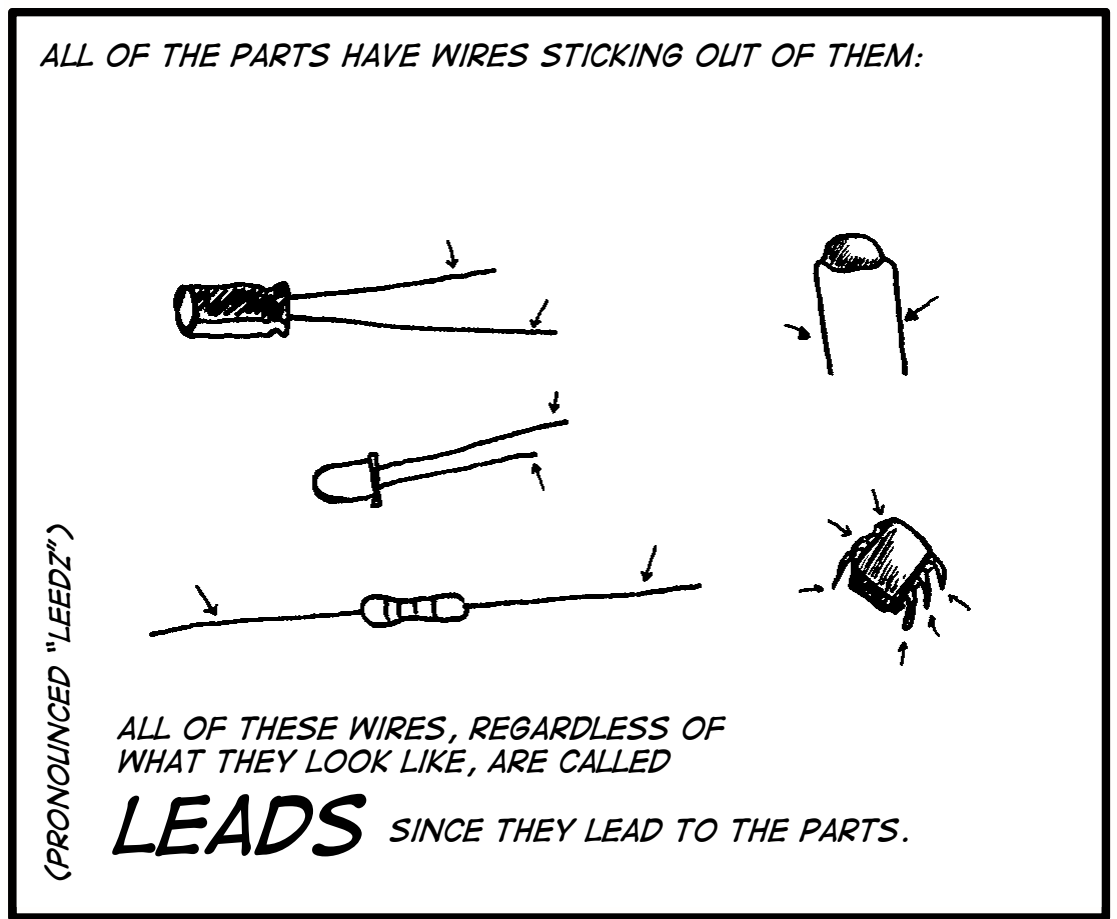
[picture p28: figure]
leads; (pronounced “leedz”); All of these wires, regardless of what they look like, are called; since they lead to the parts.

All of the parts have wires sticking out of them:

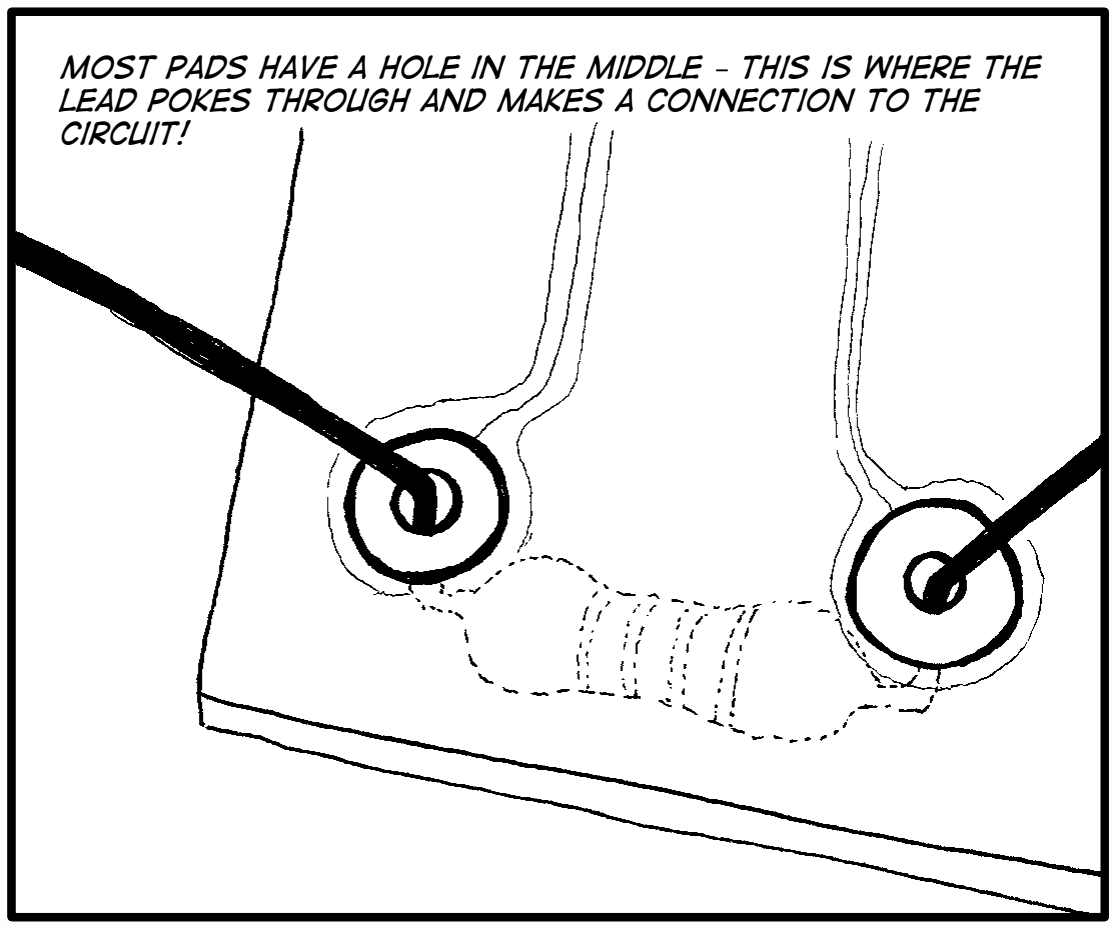
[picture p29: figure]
circuit!

Most pads have a hole in the middle – this is where the lead pokes through and makes a connection to the

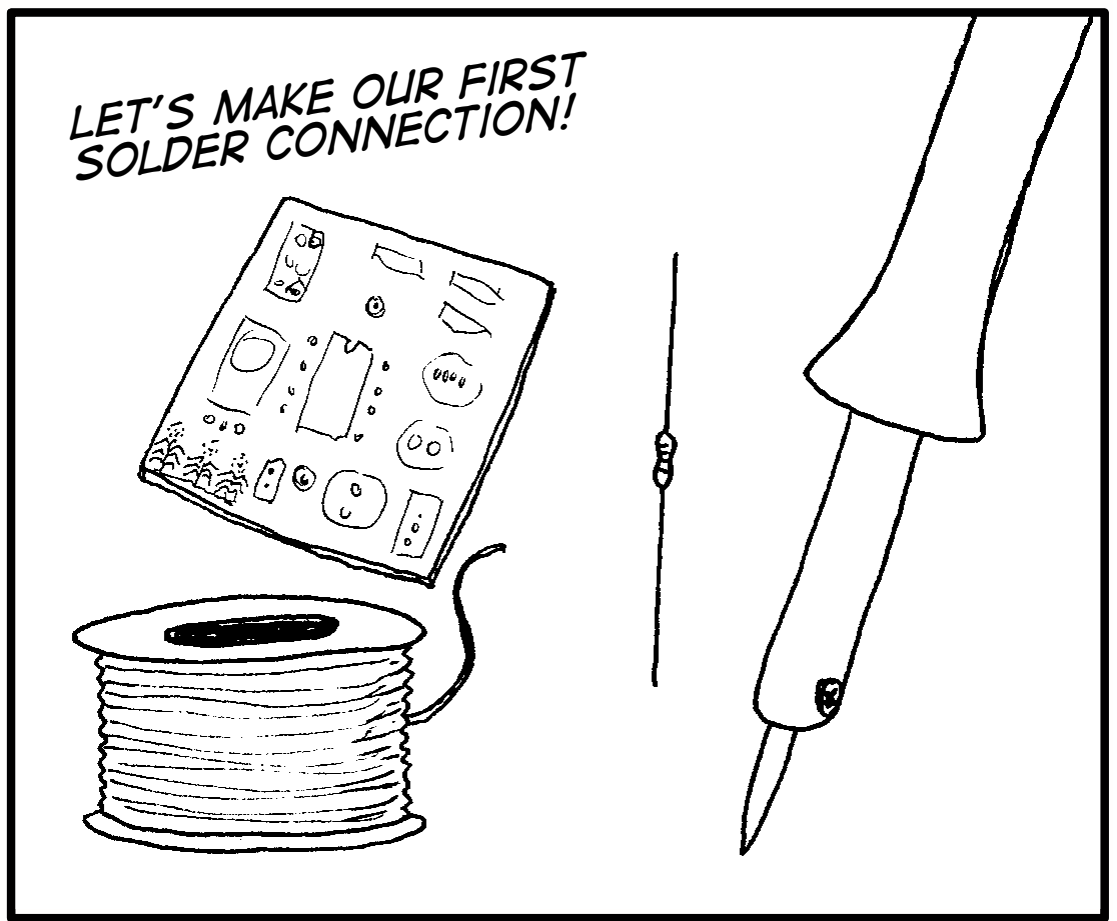
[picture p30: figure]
Let’s make our first solder connection!

If you put all of the leads from the parts into

### the correct pads for the parts

and if you put all of the parts in the correct

### orientation and if you make all good solder connections

# then the circuit will just work!

This is because the board connects everything that should be connected, and nothing that should not be connected.

some parts
can go in the
wrong way!

We’ll start with a resistor.

Resistors have two leads and (unlike some parts, such as diodes, which have a “plus” side and a “minus” side) can be placed in their pads in either direction.

PCBs usually have markings to show where each part goes (and if the orientation matters, the PCB usually has some way to show you this).

Since the word “resistor” starts with the letter “R”, the PCB usually marks places where resistors go with an “R”, followed by the resistor’s number, such as “R3”

So, to solder in the resistor, you start by finding the correct value of resistance from the project’s documentation.

Then bend the two
leads of the resistor
down the width of the
part, like this:

Then place the two
leads through the two
pads on the PCB for
this resistor.

For most PCBs, all of the parts are placed through the pads on the printed side of the PCB (which we’ll call the top of the board), and we’ll solder all of the pads on the bottom of the board.

You push the resistor’s
leads through the pads
until the part rests flat
on the PCB

(sometimes you may need to wiggle and tug gently on the leads from the bottom of the PCB to do this).

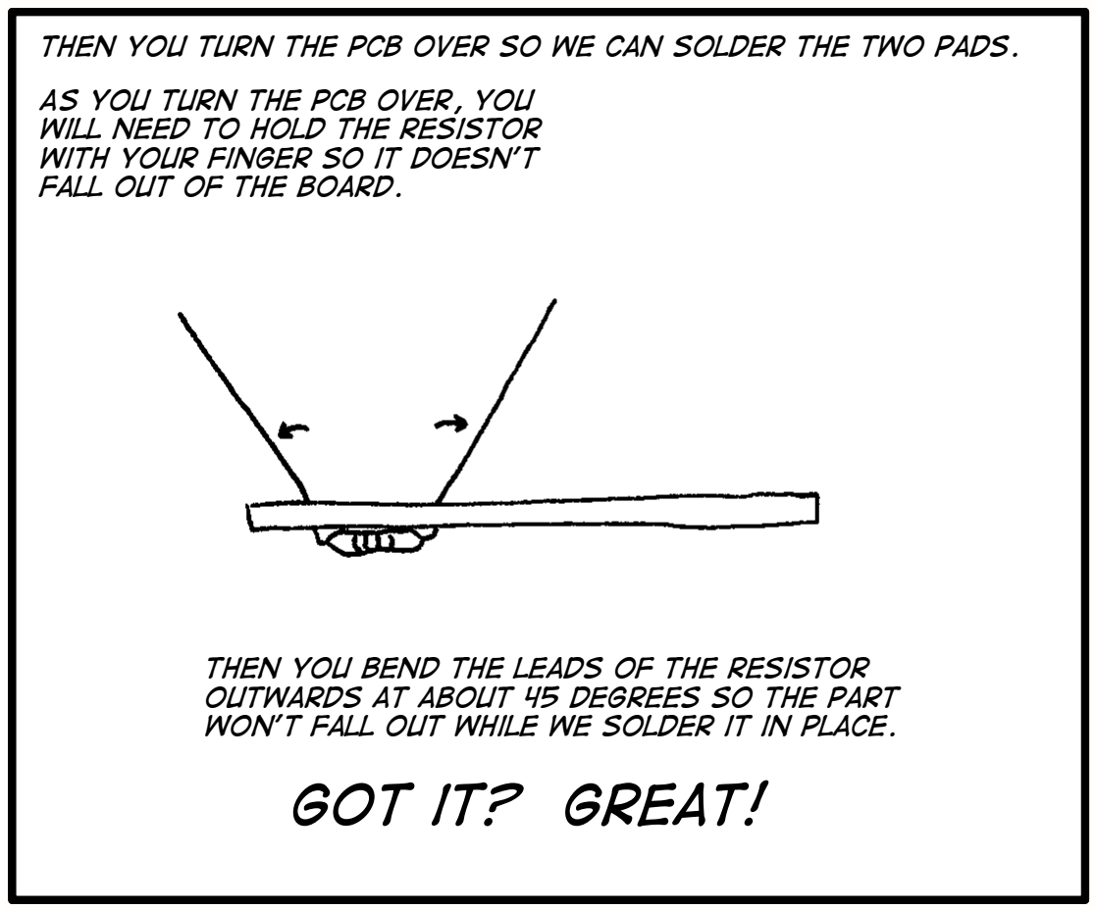
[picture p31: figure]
As you turn the PCB over, you will need to hold the resistor with your finger so it doesn’t fall out of the board.; then you bend the leads of the resistor; Got it? Great!
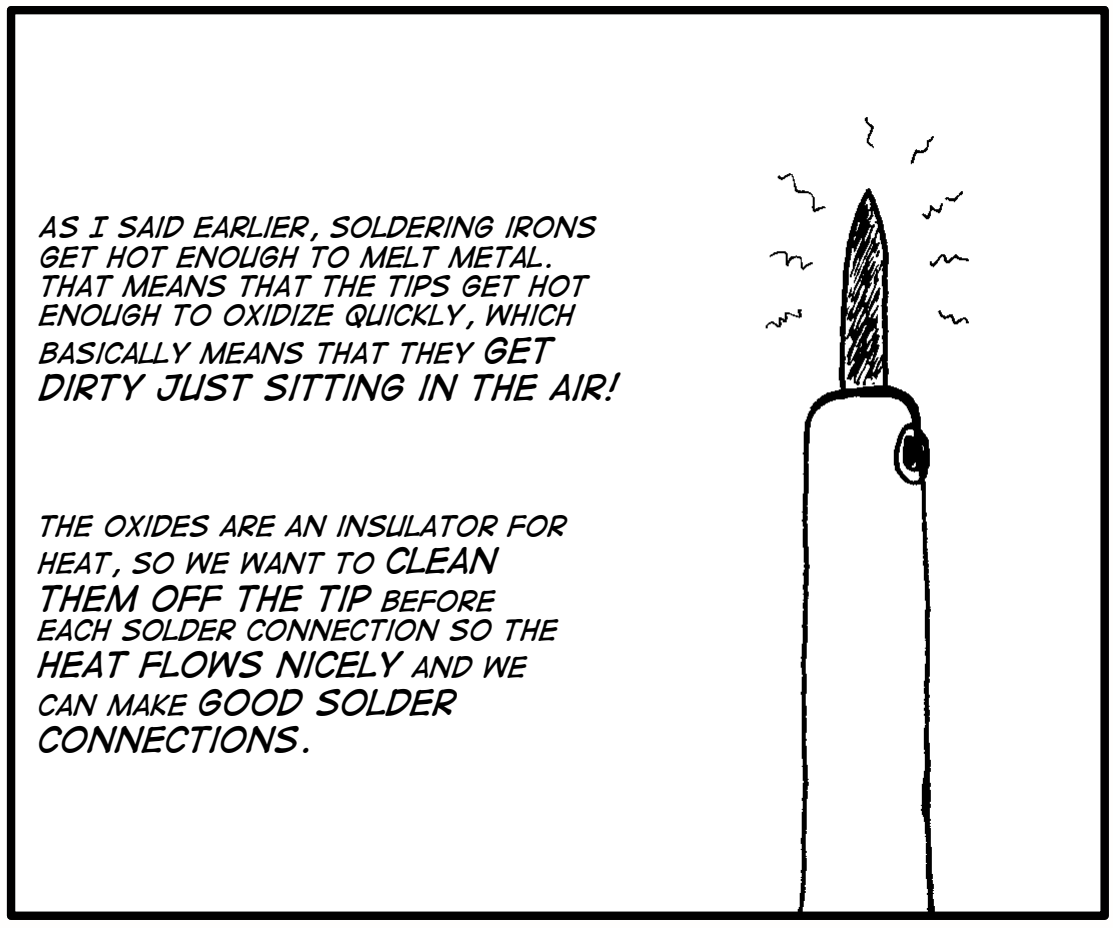
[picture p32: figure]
As I said earlier, soldering irons get hot enough to melt metal. That means that the tips get hot enough to oxidize quickly, which basically means that they get dirty just sitting in the air!; The oxides are an insulator for heat, so we want to clean them off the tip before each solder connection so the heat flows nicely and we can make good solder connections.

Then you turn the PCB over so we can solder the two pads.

outwards at about 45 degrees so the part won’t fall out while we solder it in place.

This is why we have a wet sponge:
to clean the oxides off the tip. Just scrape the
tip across the sponge gently,

### then rotate the iron and scrape gently

across the sponge again.

This should make the tip silvery and somewhat shiny – ready

### to solder. Remember to clean the tip like this before each connection you make – the tips oxidize

quickly!

### If the tip is nice and silvery and shiny, you

can make good connections.

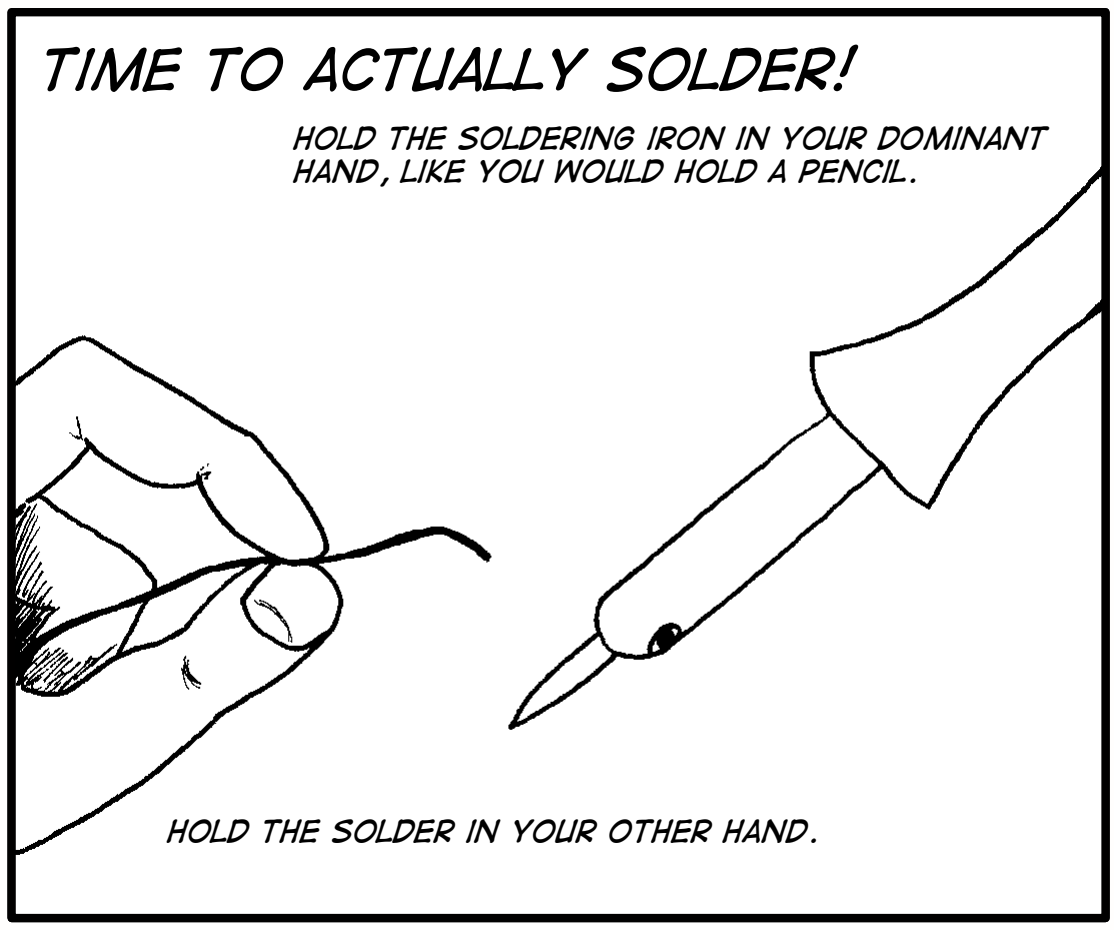
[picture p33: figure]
Time to actually solder!; hand, like you would hold a pencil.; Hold the solder in your other hand.

Hold the soldering iron in your dominant

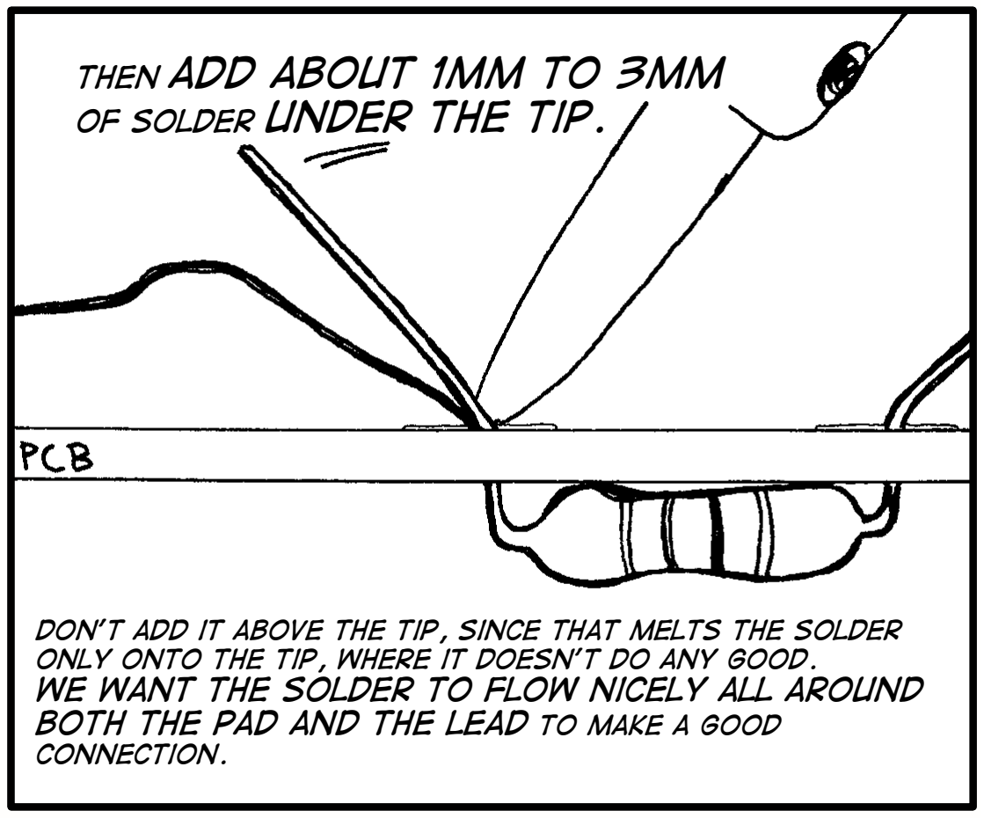
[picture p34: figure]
Then add about 1mm to 3mm of solder under the tip.; connection.

Don’t add it above the tip, since that melts the solder only onto the tip, where it doesn’t do any good.

### we want the solder to flow nicely all around both the pad and the lead to make a good

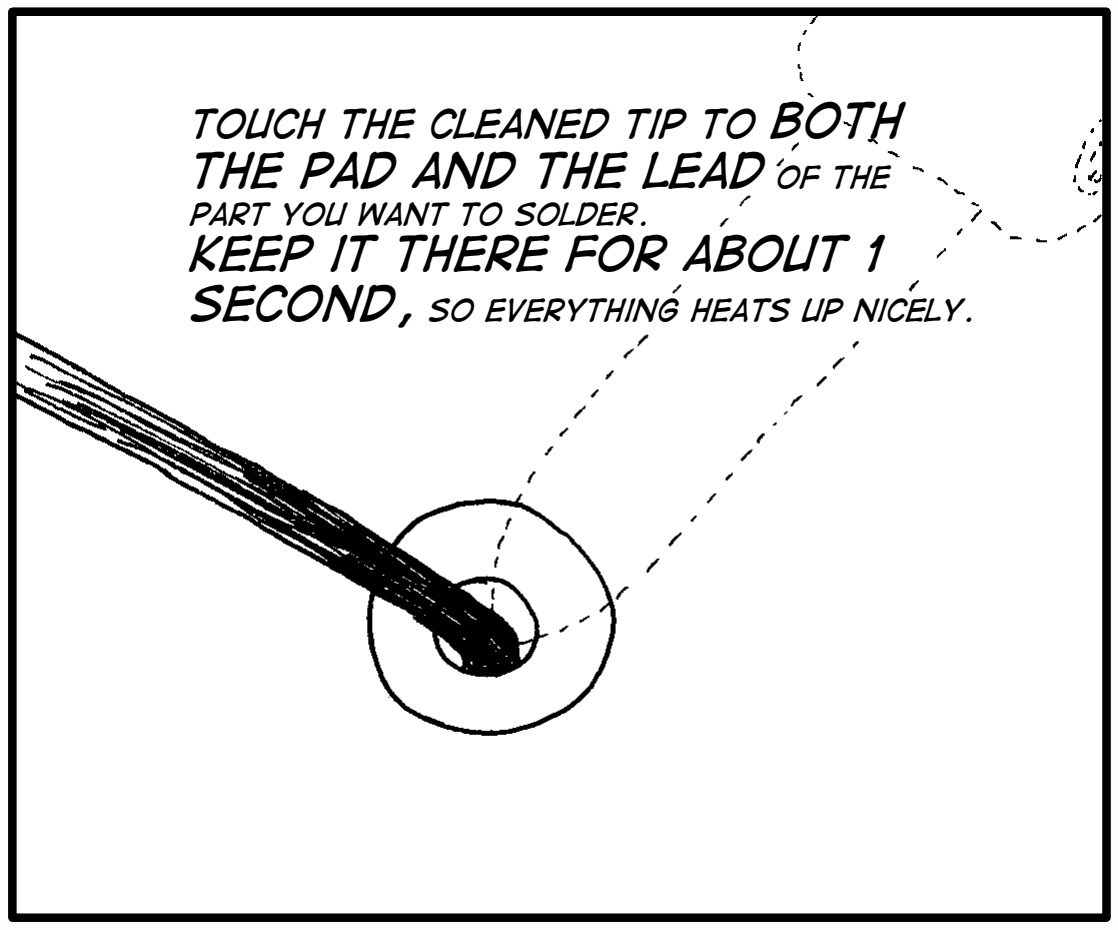
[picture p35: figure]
Touch the cleaned tip to both the pad and the lead of the; part you want to solder. Keep it there for about 1; second, so everything heats up nicely.
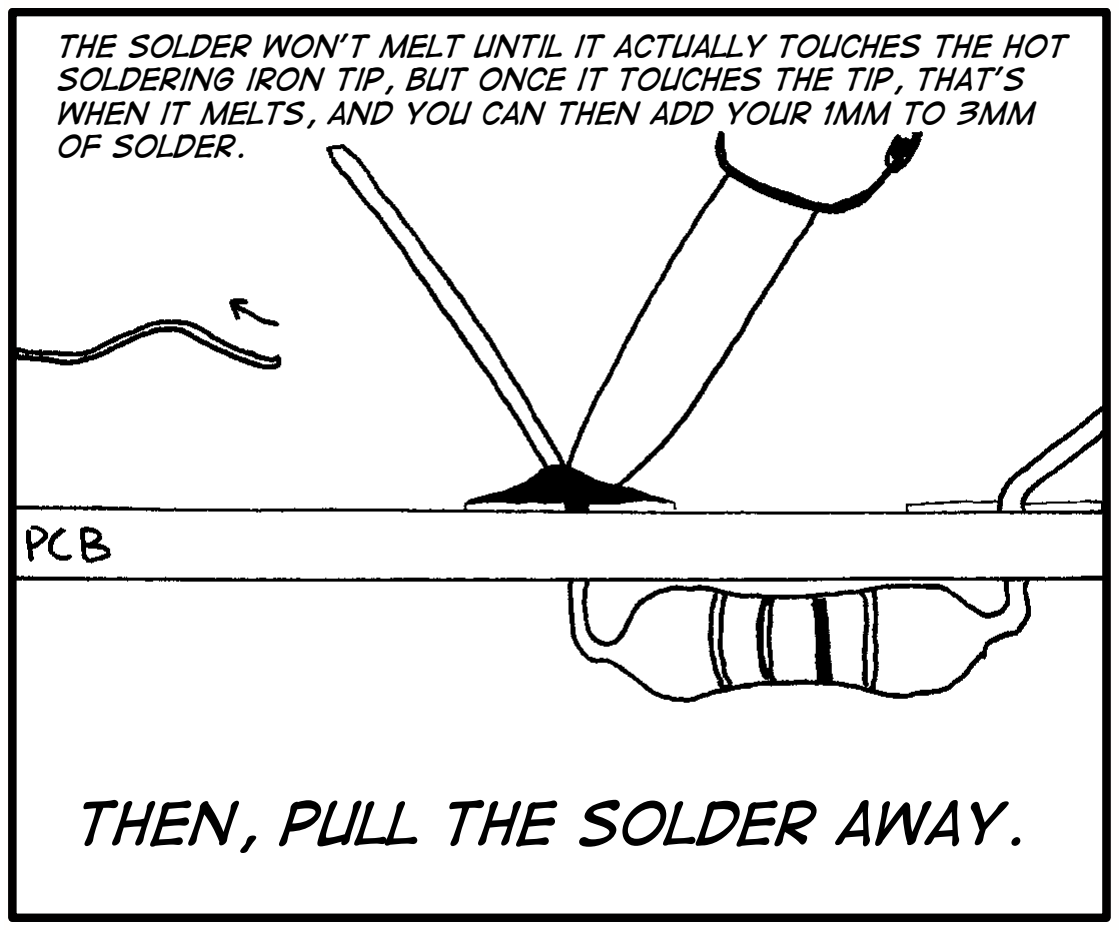
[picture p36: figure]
of solder.; Then, pull the solder away.

The solder won’t melt until it actually touches the hot soldering iron tip, but once it touches the tip, that’s when it melts, and you can then add your 1mm to 3mm

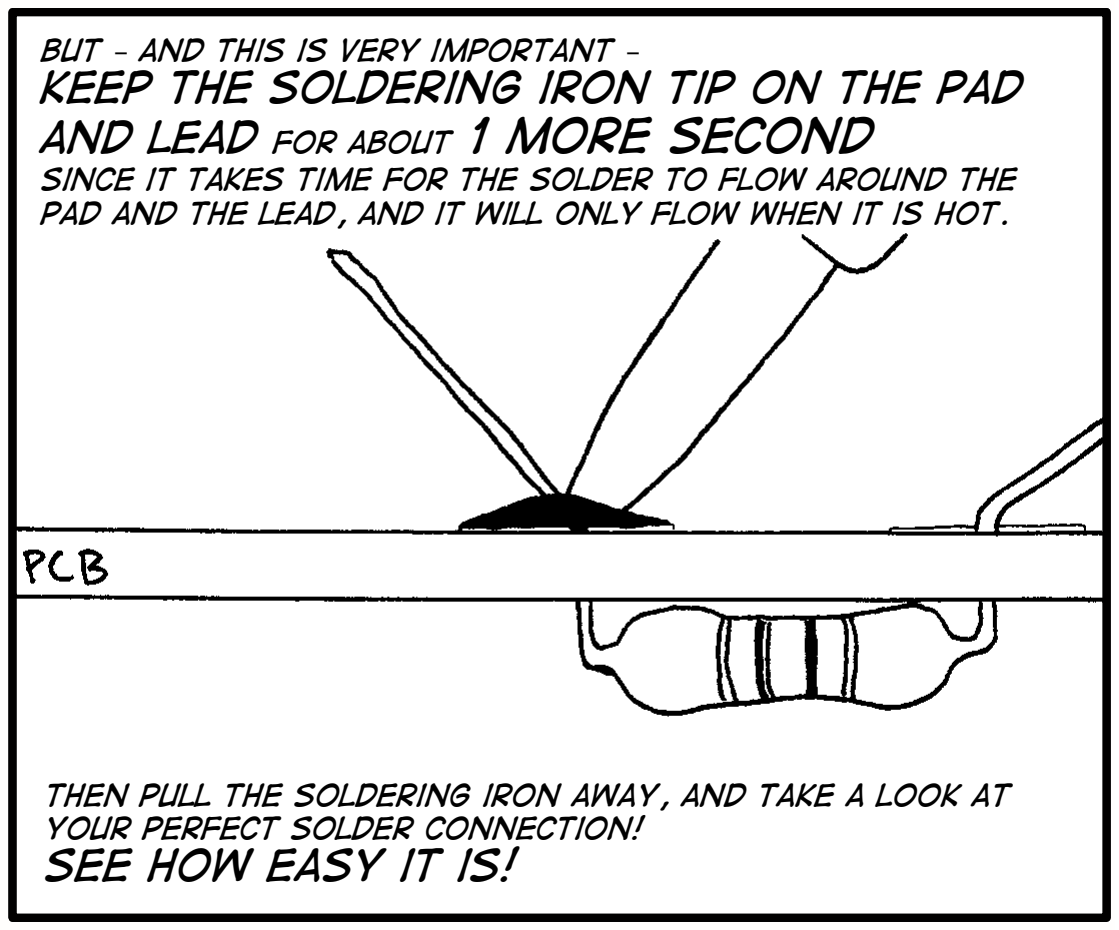
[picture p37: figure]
But – and this is VERY important – keep the soldering iron tip on the pad and lead for about 1 more second; your perfect solder connection! See how easy it is!

since it takes time for the solder to flow around the pad and the lead, and it will only flow when it is hot.

Then pull the soldering iron away, and take a look at

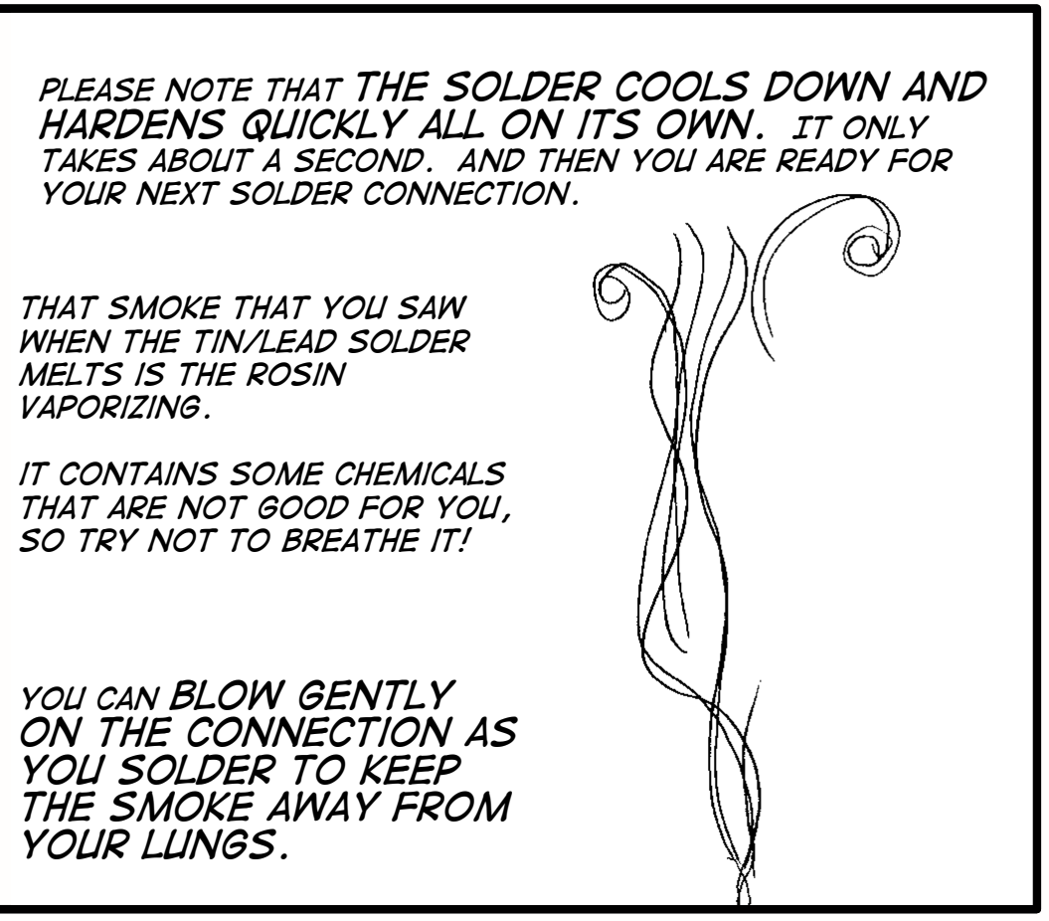
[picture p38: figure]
hardens quickly all on its own. It only; your next solder connection.; That smoke that you saw when the tin/lead solder melts is the rosin vaporizing.; it contains some chemicals that are not good for you, so try not to breathe it!; you can blow gently on the connection as you solder to keep the smoke away from your lungs.

## Please note that the solder cools down and

takes about a second. And then you are ready for

### Now put that soldering iron back in its stand

while we’re not using it.

## The stand keeps the hot iron safely on the

table. Most people say that it’s not fun to have it land in your lap!

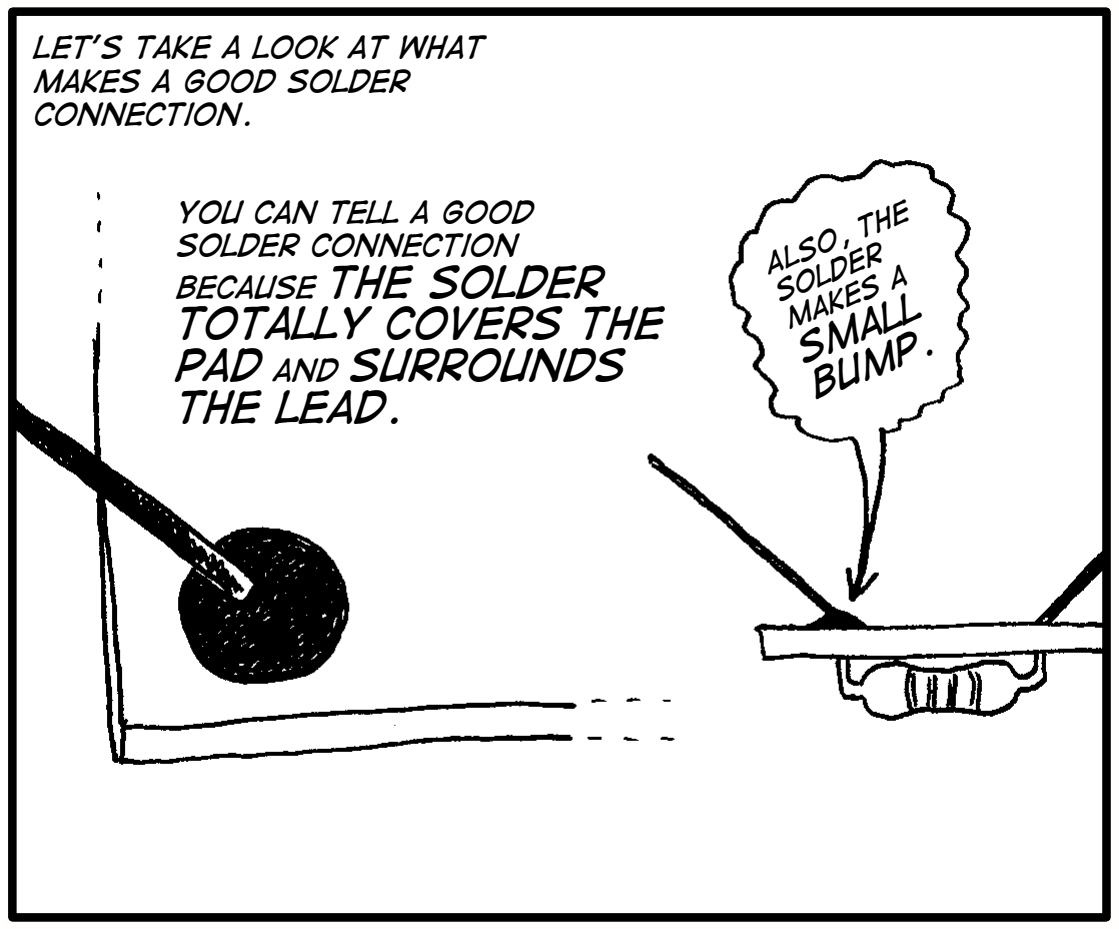
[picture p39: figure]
Let’s take a look at what makes a good solder connection.; You can tell a good solder connection because the solder totally covers the pad and surrounds the lead.; Also, the solder makes a small bump.
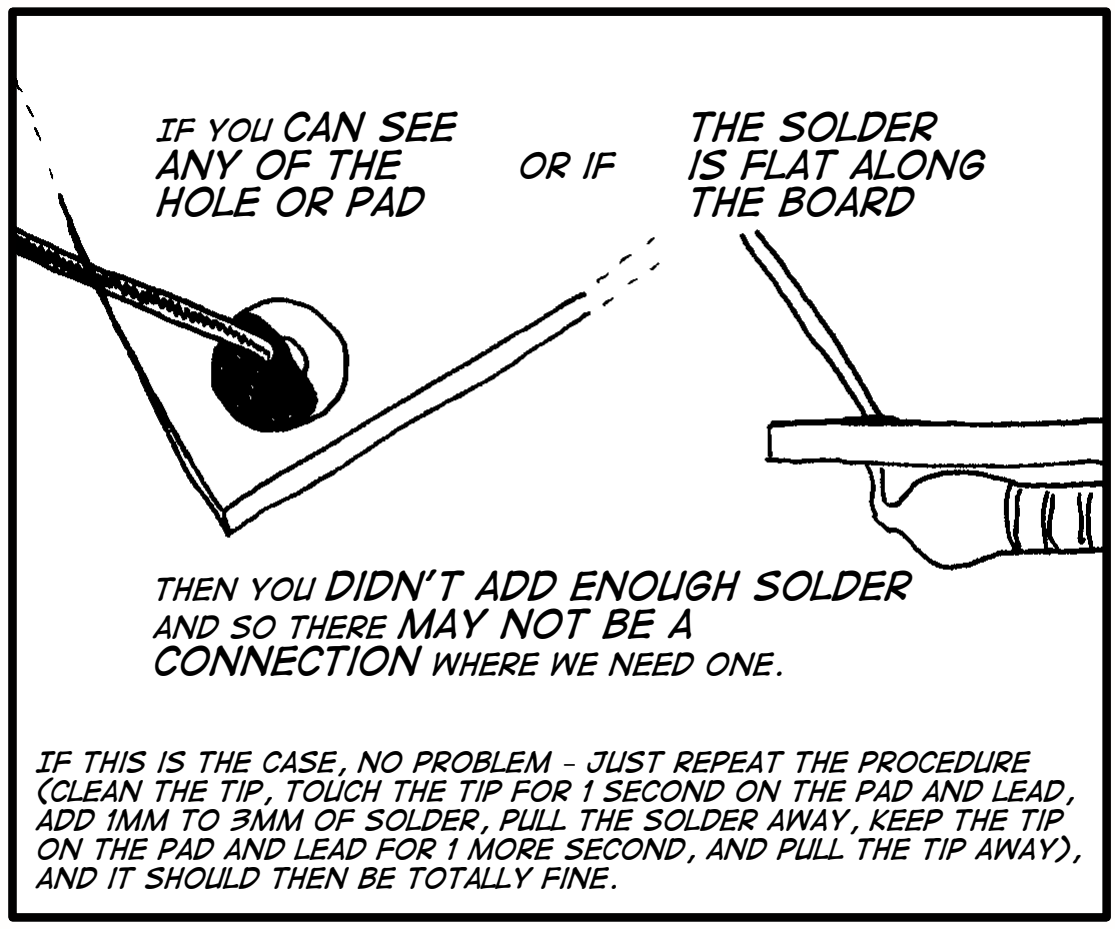
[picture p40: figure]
If you can see any of the hole or pad; then you didn’t add enough solder and so there may not be a connection where we need one.; and it should then be totally fine.; the solder is flat along the board

If this is the case, no problem – just repeat the procedure (clean the tip, touch the tip for 1 second on the pad and lead, add 1mm to 3mm of solder, pull the solder away, keep the tip on the pad and lead for 1 more second, and pull the tip away),

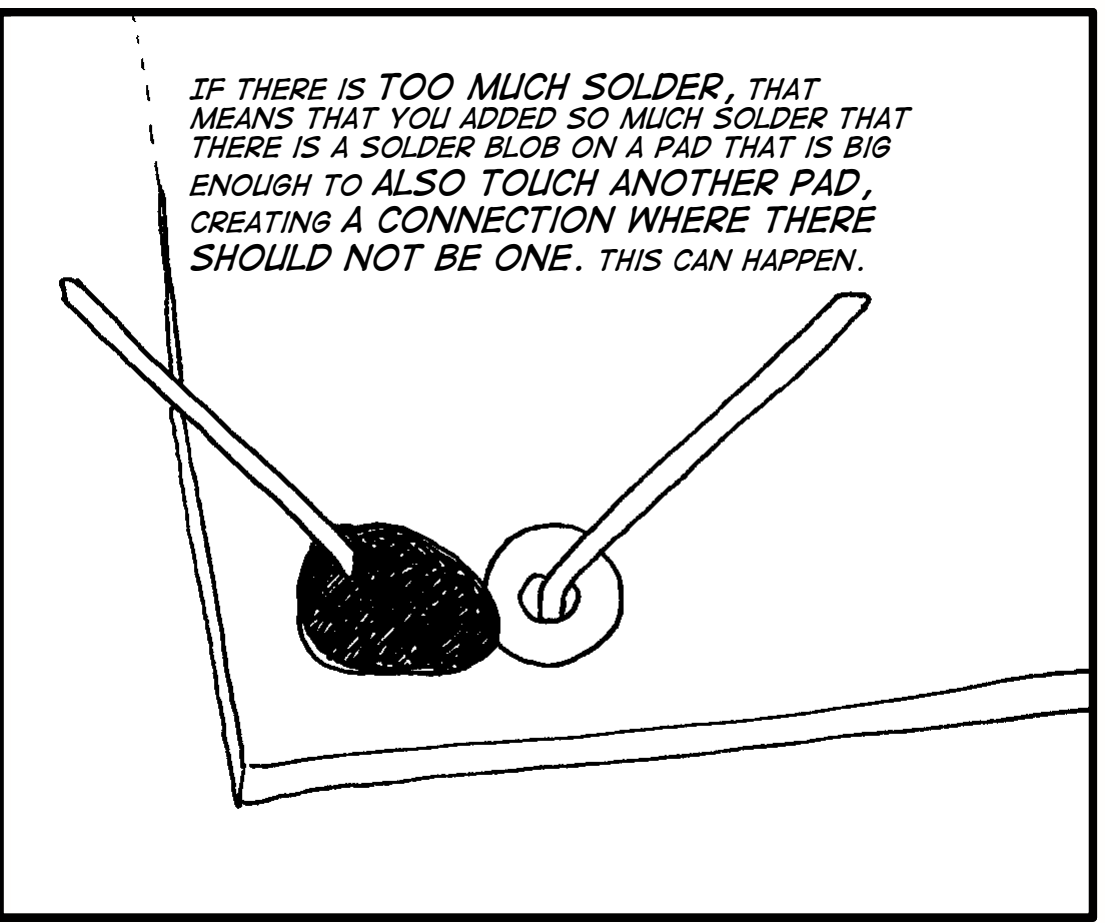
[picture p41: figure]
If there is too much solder, that; enough to also touch another pad, creating a connection where there should not be one. This can happen.

means that you added so much solder that there is a solder blob on a pad that is big

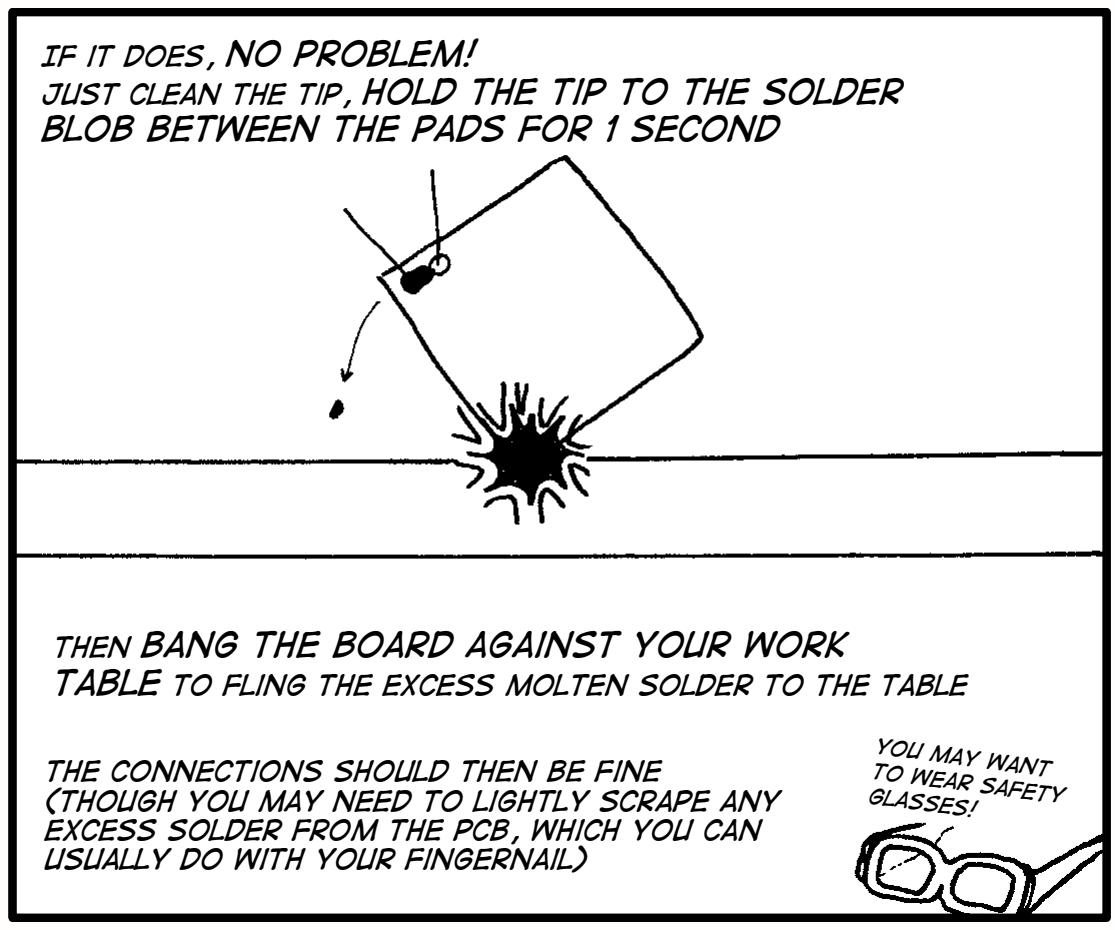
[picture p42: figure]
If it does, no problem!; blob between the pads for 1 second; then bang the board against your work; you may want to wear safety glasses!; The connections should then be fine; usually do with your fingernail)

### just clean the tip, hold the tip to the solder

table to fling the excess molten solder to the table

(though you may need to lightly scrape any
excess solder from the PCB, which you can

### In between too much and

too little solder is a
lot of leeway.
This is one reason why
soldering is easy.

Both
good! good too!

Some people like to solder parts to their pads after adding a bunch of parts to the board.

I prefer to add and solder only one part

## to the board at a time. I find this easier

since there aren’t so many leads that can get in the way of my soldering iron.

Also, if I add more than one part to the board I sometimes miss soldering a pad, since it isn’t so easy (as you might think it would be) to see which connections are soldered.

After soldering all of the leads of the part you are soldering, it is time to cut off the
excess leads.
This must be done to ensure that the excess leads do not bend over and short to another lead or pad.

if this happens, then there will be a
connection where we do not want one.

To cut the lead, we’ll use a
small wire cutter.

### One side has flat cutting

edges, and the other side has a deep groove.

### Place the flat edge down, parallel to the PCB, just at the top of the little bump of

solder.

### squeeze the handles, and the cutting edges

snap shut.

which turns the
excess lead into a

## projectile that hits you right in your eye!

## Safety tip #3 (of 3): ALWAYS hold the lead you are cutting with one hand while

you cut with your other hand.

If you always do this, you will always be safe.

you may
also
want

to wear
safety
glasses!

If the excess lead is too short to hold onto (but long enough to potentially short out to something on your PCB),
then position the wire cutter,

## hold your fingers over

the lead,

this will keep the
excess lead from
hitting anyone in
the eye (or
shorting out
somewhere on
your project)

and then squeeze.

Leads that are already very short, such as IC sockets, do not need to be cut – they have leads that are too short to bend over and make shorts.

If you make a mistake, it is totally OK.

## All mistakes are fixable (though some

are easier than others).

## And making mistakes is how we

learn to become better at everything we
do.
While soldering is easy, unsoldering

## takes lots of practice. And if you

make a mistake, you get to have some practice!

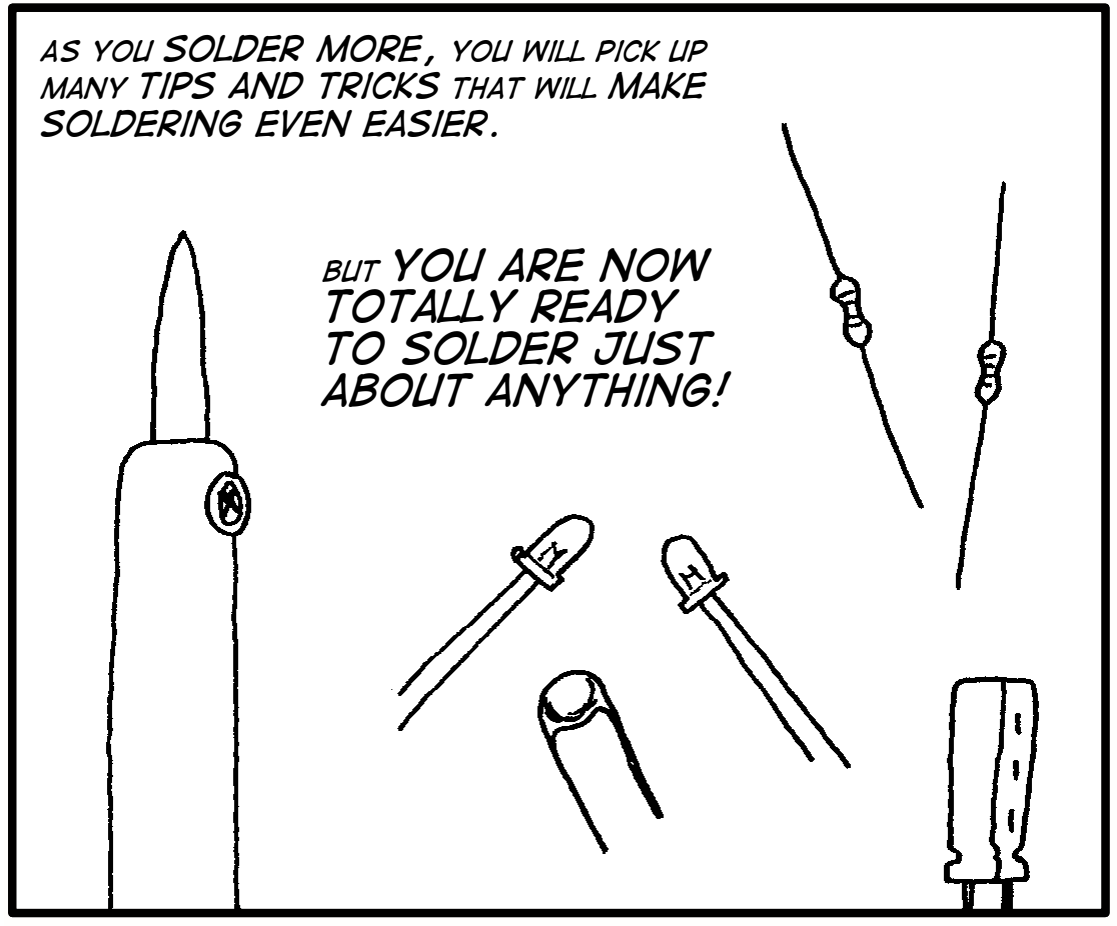
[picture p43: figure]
As you solder more, you will pick up many tips and tricks that will make soldering even easier.; But you are now totally ready to solder just about anything!

If you like soldering, and want to solder well, you’ll want to buy some good tools.

### But you do not need to spend a lot

of money to get them.

You can buy a decent soldering iron (in the shape of a long, fat pencil) for about US$15

You’ll need a

### soldering iron

stand that fits a
wet sponge,
which will cost you
about US$6

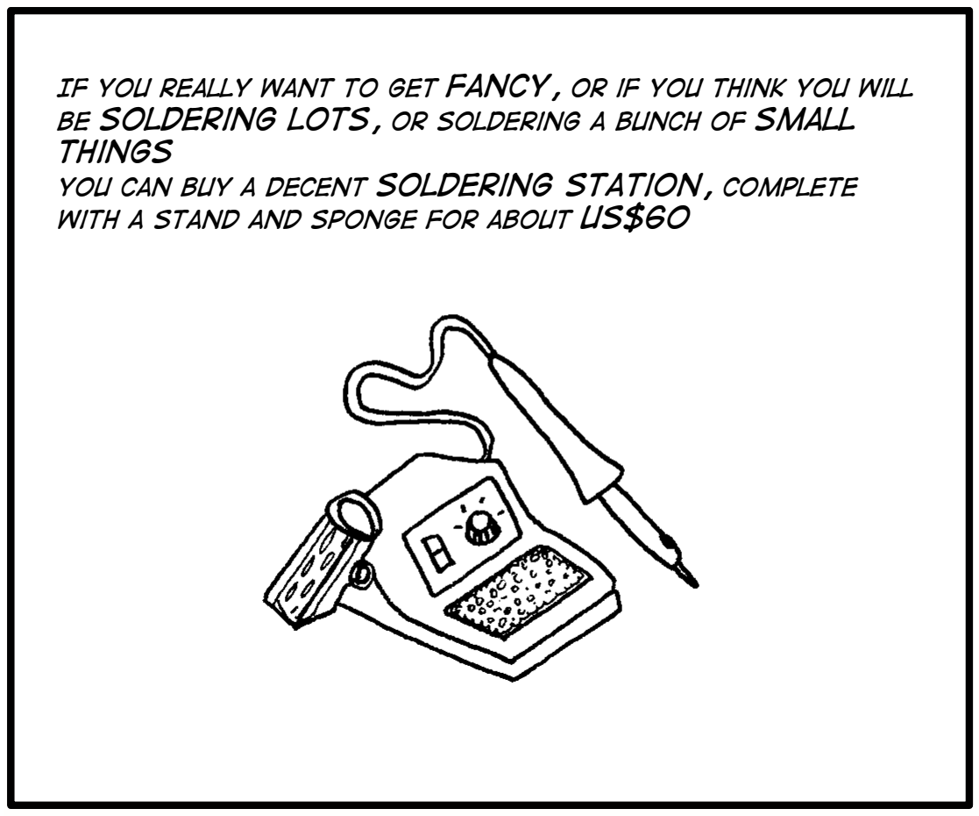
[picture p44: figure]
things; with a stand and sponge for about US$60

If you really want to get fancy, or if you think you will be soldering lots, or soldering a bunch of small

you can buy a decent soldering station, complete

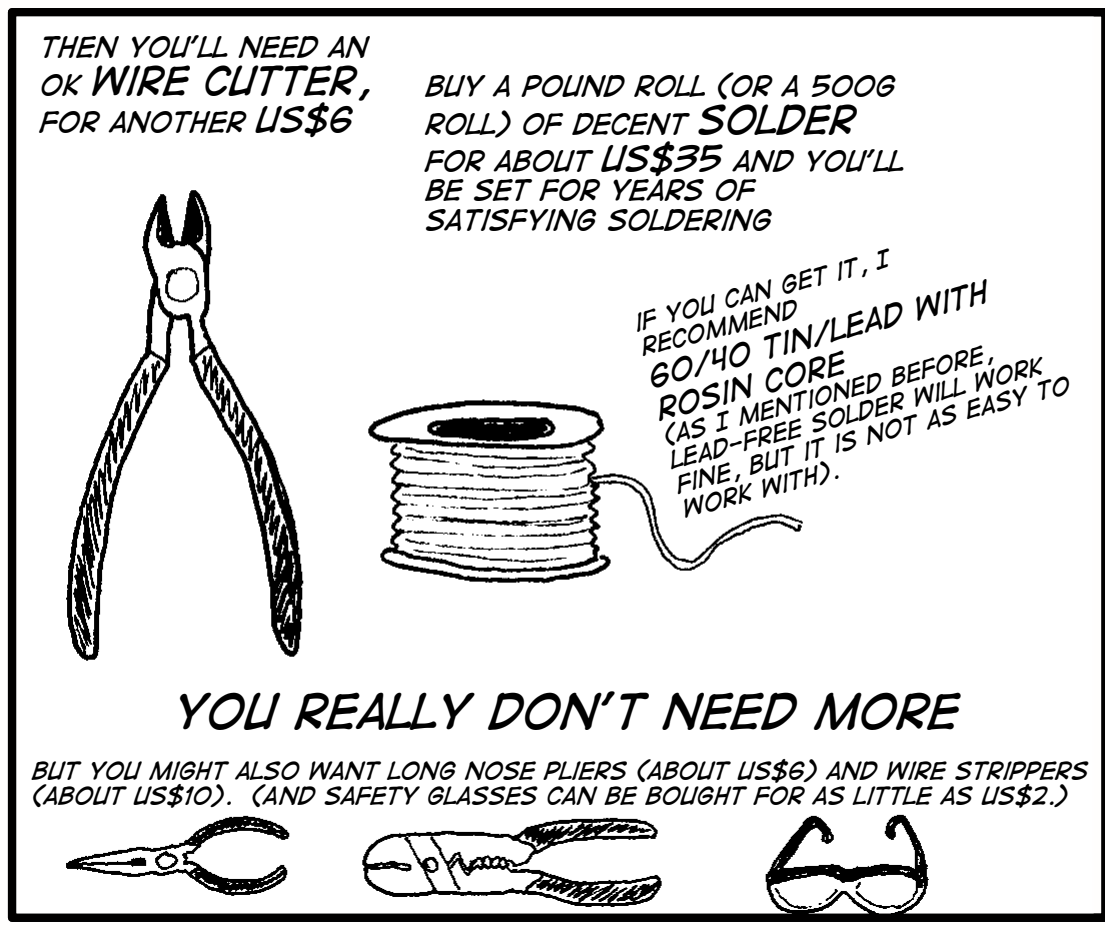
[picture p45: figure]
Then you’ll need an OK wire cutter, for another US$6; Buy a pound roll (or a 500g roll) of decent solder for about US$35 and you’ll be set for years of satisfying soldering; if you can get it, I; recommend; 60/40 tin/lead with; rosin core; (as I mentioned before, lead-free solder will work fine, but it is not as easy to; work with).; You really don’t need more

But you might also want long nose pliers (about US$6) and wire strippers (about US$10). (And safety glasses can be bought for as little as US$2.)

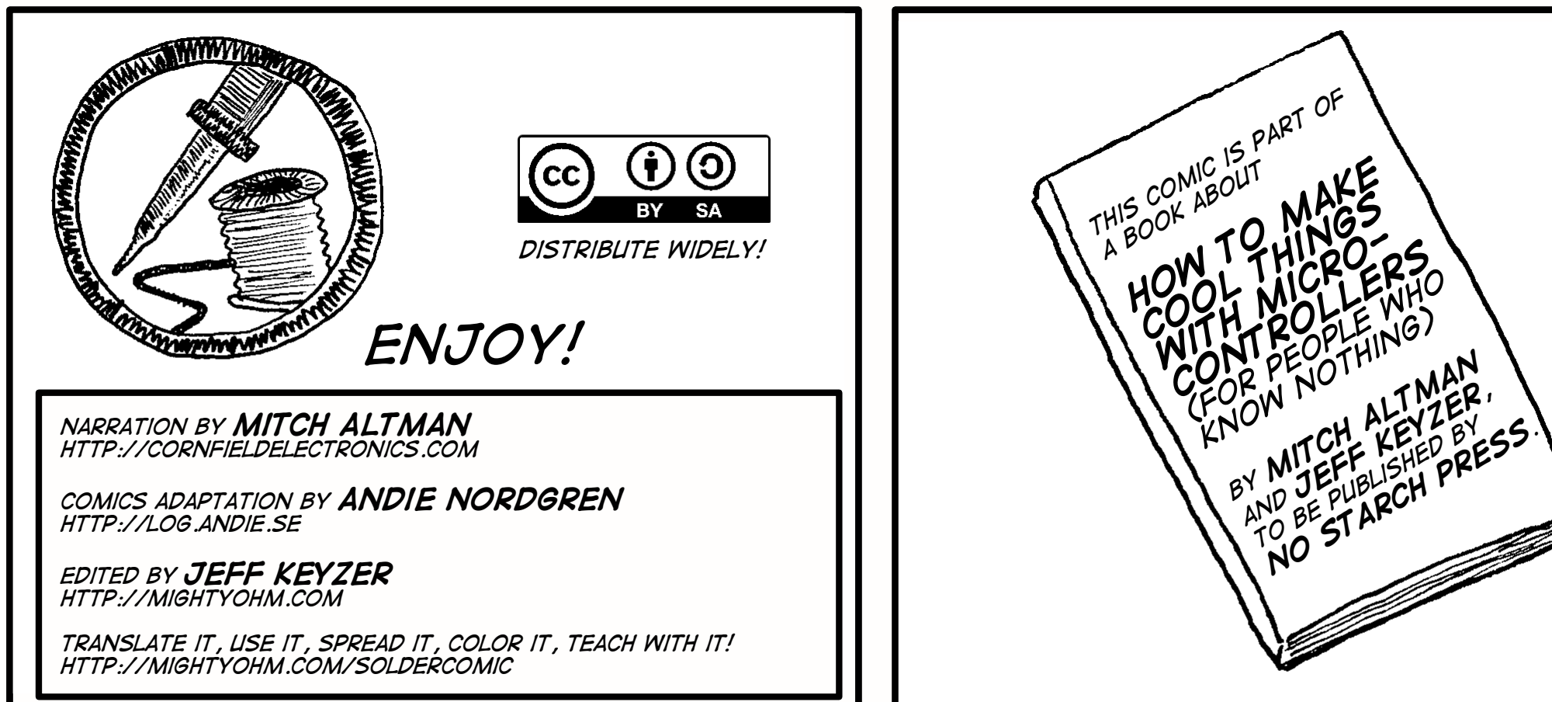
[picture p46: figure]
Narration by Mitch Altman; http://cornfieldelectronics.com; COmics adaptation by Andie Nordgren http://log.andie.se; Edited by Jeff Keyzer http://mightyohm.com; http://mightyohm.com/soldercomic; Distribute widely! Enjoy!
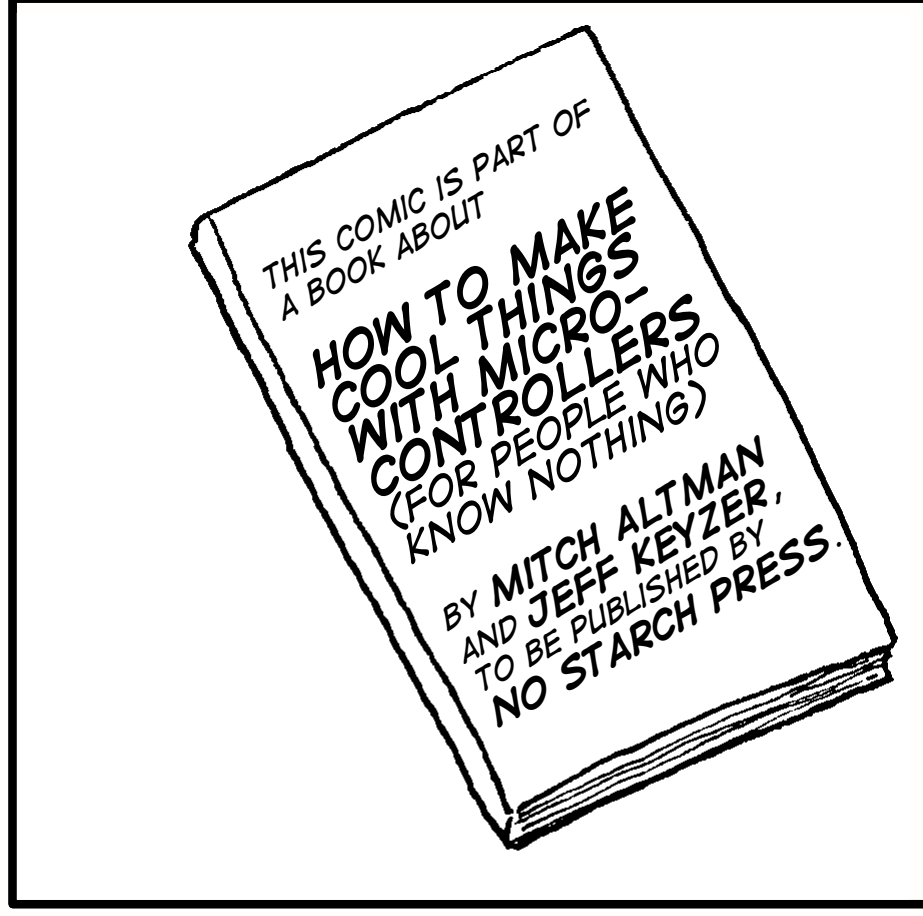
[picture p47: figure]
This comic is part of; a book about; How to Make Cool Things with Micro- controllers (For People Who Know Nothing) by Mitch Altman and Jeff Keyzer, to be published by No Starch Press

Translate it, use it, spread it, color it, teach with it!

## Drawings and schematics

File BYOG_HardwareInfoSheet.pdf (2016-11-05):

# Hardware Info Sheet

74HC595

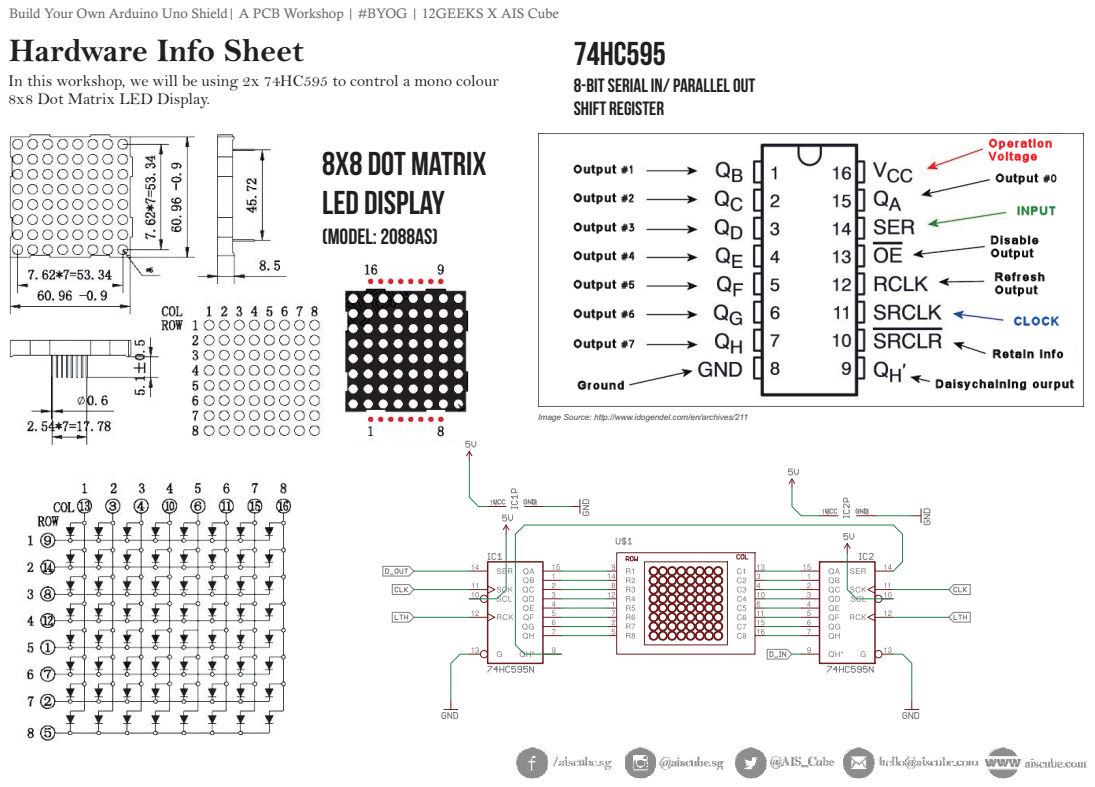
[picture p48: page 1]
Build Your Own Arduino Uno Shield| A PCB Workshop | #BYOG; 12GEEKS X |; AIS Cube; 8x8 Dot Matrix; LED display; (model: 2088AS)

In this workshop, we will be using 2x 74HC595 to control a mono colour
8x8 Dot Matrix LED Display.

8-bit serial in/ parallel out
shift register

Image Source: http://www.idogendel.com/en/archives/211

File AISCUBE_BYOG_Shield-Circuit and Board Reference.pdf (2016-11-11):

# EAGLE Schematics & Board Layout Reference

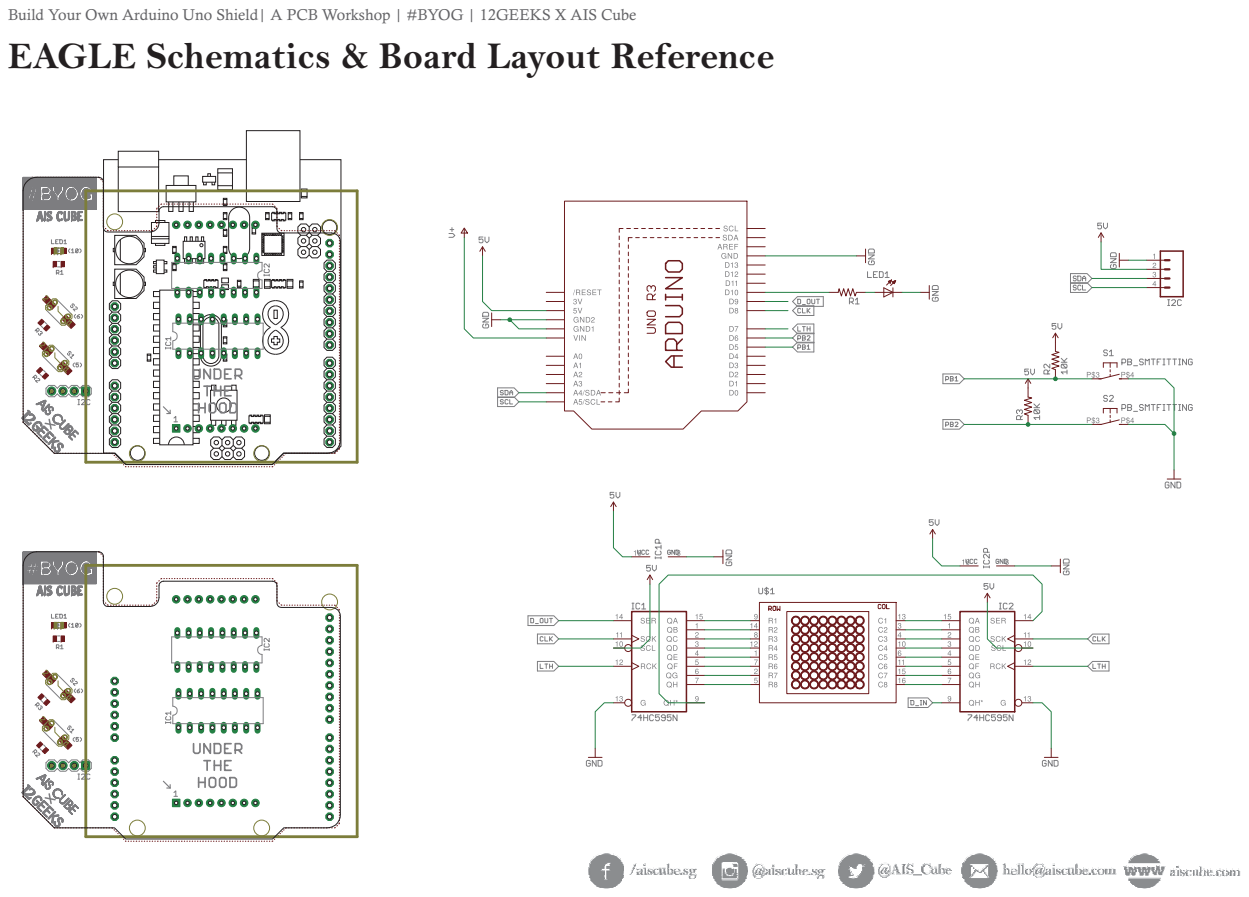
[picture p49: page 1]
Build Your Own Arduino Uno Shield| A PCB Workshop | #BYOG; 12GEEKS X |; AIS Cube

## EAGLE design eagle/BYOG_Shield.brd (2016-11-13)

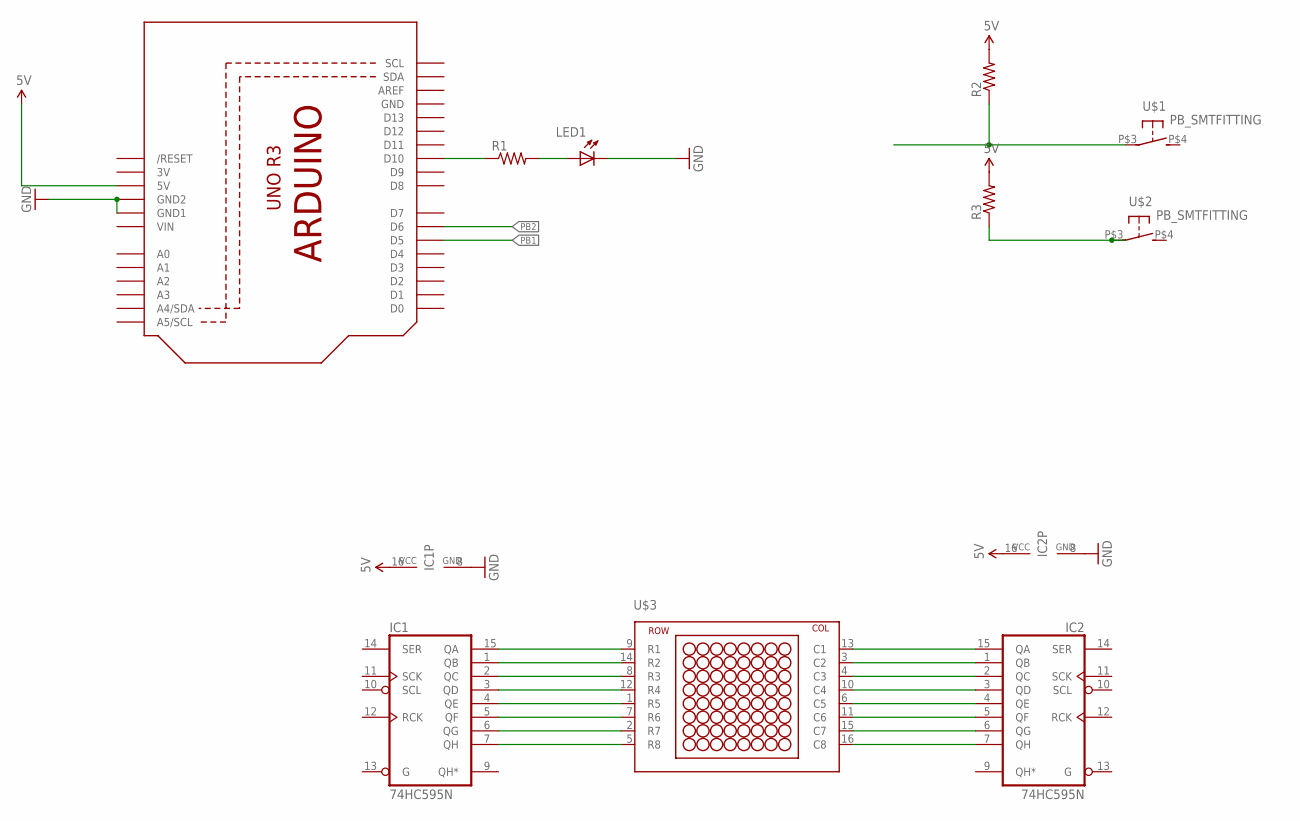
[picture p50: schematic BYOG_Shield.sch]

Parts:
IC1, IC2: 74HC595N; DIL16
LED1: LED/0805; CHIP-LED0805
R1, R2, R3: RESISTOR0805-RES; 0805
U1: ARDUINOR3-NOIOREF-NOTEXT; ARDUINOR3-NOTEXT-NOIOREF
U$1, U$2: PB_SMTFITTING; PB_SMT_TIGHT
U$3: 8X8DM_2088AS

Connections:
3V: U1.3V
5V: IC1.16 (VCC), IC2.16 (VCC), R2.2, R3.2, U1.5V
GND: IC1.8 (GND), IC2.8 (GND), LED1.C, U1.GND, U1.GND1, U1.GND2
unnamed: R1.1, U1.D10
unnamed: LED1.A, R1.2
unnamed: R2.1, U$1.P$3 (1)
unnamed: R3.1, U$2.P$3 (1)
unnamed: IC1.1 (QB), U$3.14 (R2)
unnamed: IC1.2 (QC), U$3.8 (R3)
unnamed: IC1.3 (QD), U$3.12 (R4)
unnamed: IC1.4 (QE), U$3.1 (R5)
unnamed: IC1.5 (QF), U$3.7 (R6)
unnamed: IC1.6 (QG), U$3.2 (R7)
unnamed: IC1.7 (QH), U$3.5 (R8)
unnamed: IC1.15 (QA), U$3.9 (R1)
unnamed: IC2.1 (QB), U$3.3 (C2)
unnamed: IC2.2 (QC), U$3.4 (C3)
unnamed: IC2.3 (QD), U$3.10 (C4)
unnamed: IC2.4 (QE), U$3.6 (C5)
unnamed: IC2.5 (QF), U$3.11 (C6)
unnamed: IC2.6 (QG), U$3.15 (C7)
unnamed: IC2.7 (QH), U$3.16 (C8)
unnamed: IC2.15 (QA), U$3.13 (C1)
PB1: U1.D5
PB2: U1.D6
VIN: U1.VIN

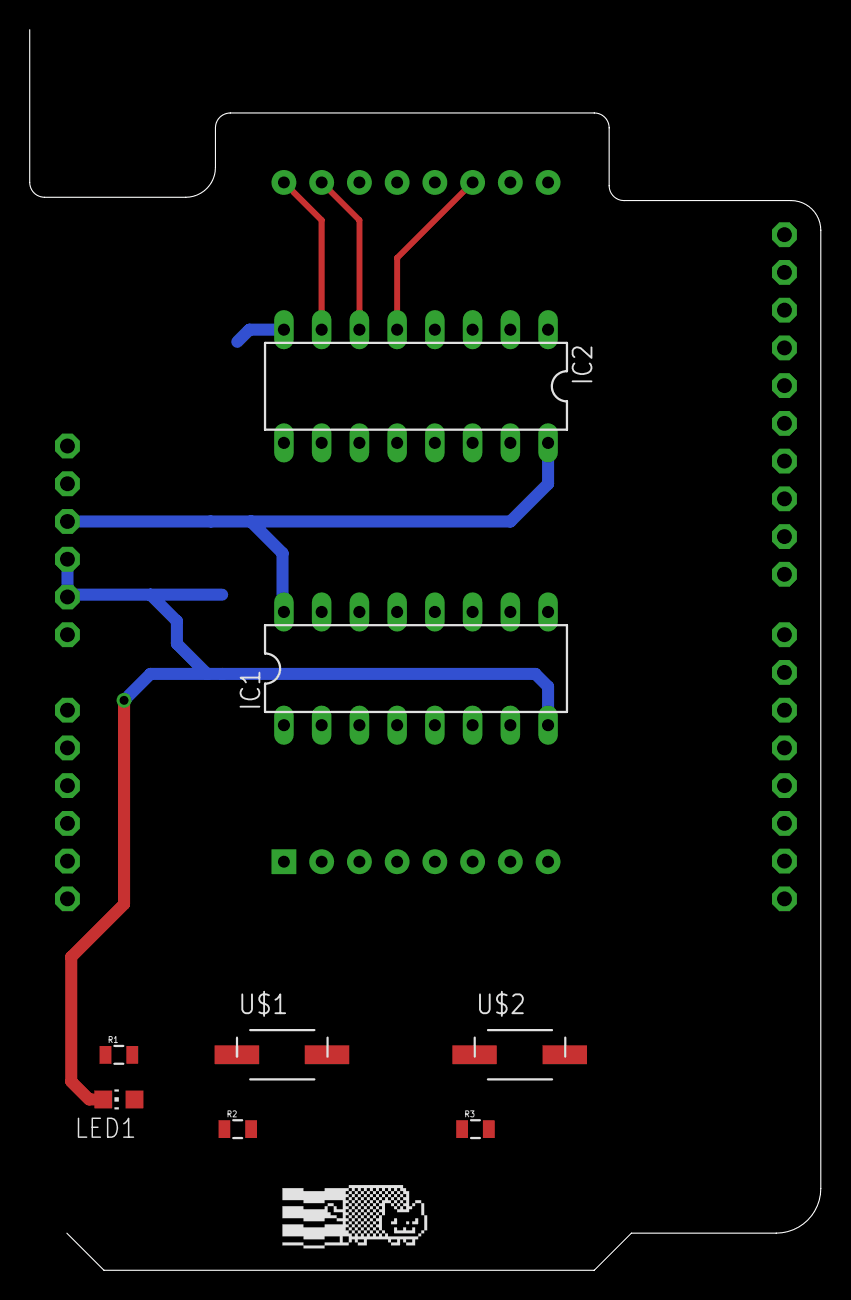
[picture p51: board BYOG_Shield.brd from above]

Board: 2 copper layers, 53.2 x 83.5 mm, 11 parts (0 on the bottom side), 22 nets.

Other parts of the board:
U$8: LOGO_NYAN

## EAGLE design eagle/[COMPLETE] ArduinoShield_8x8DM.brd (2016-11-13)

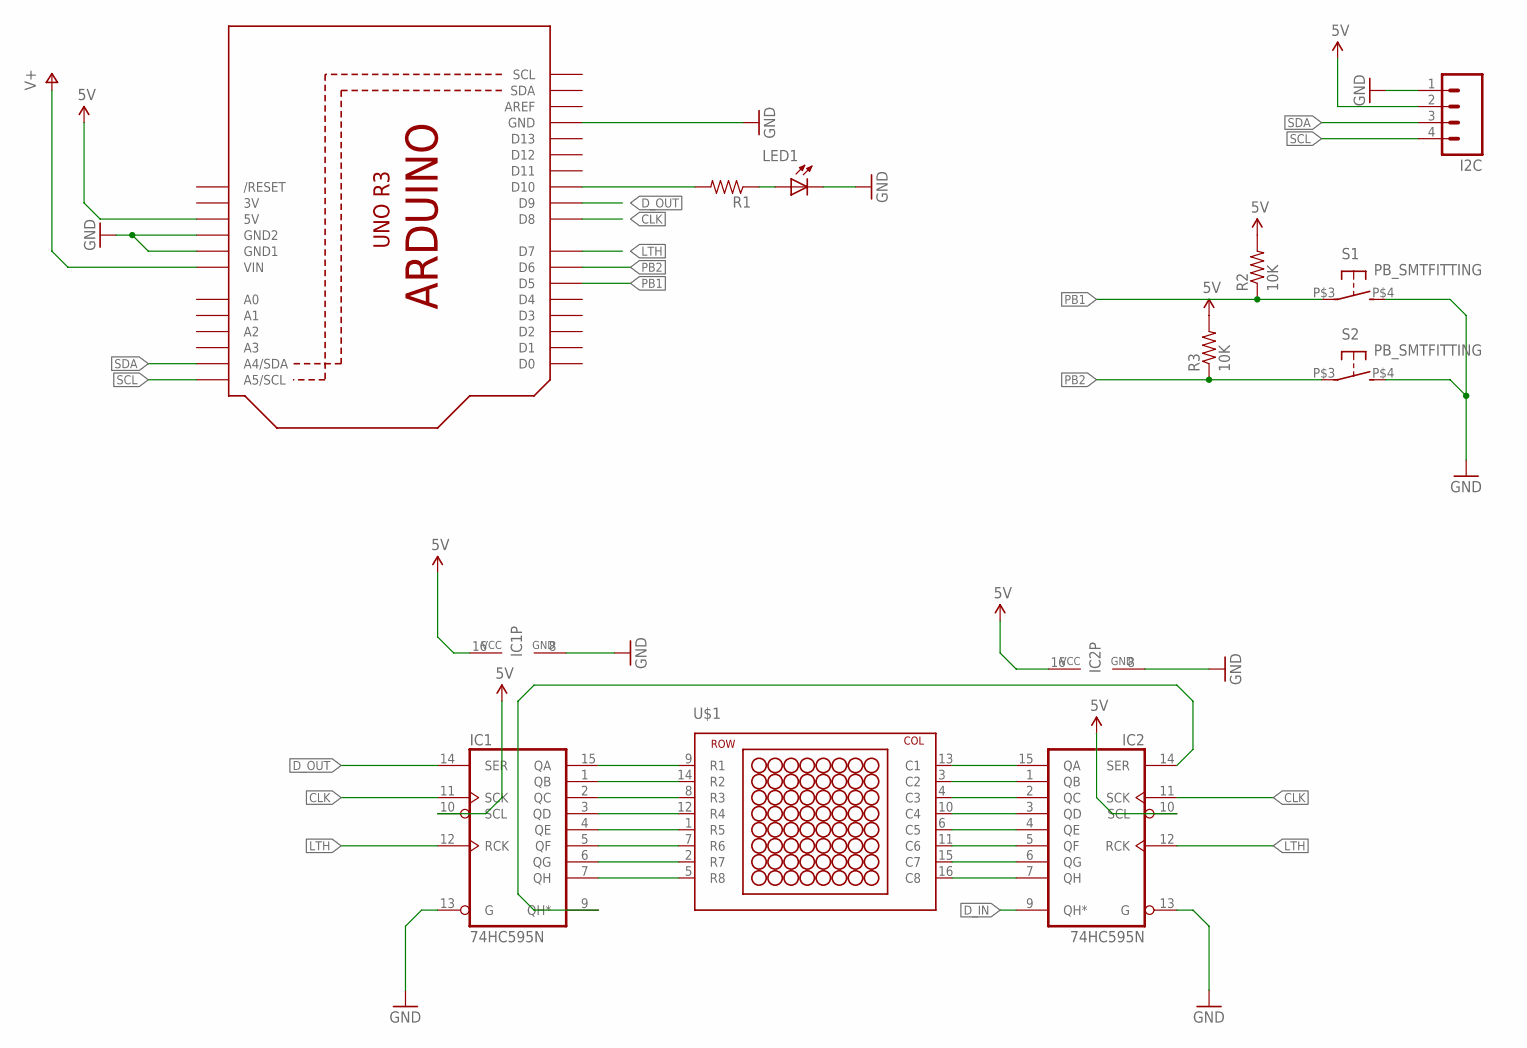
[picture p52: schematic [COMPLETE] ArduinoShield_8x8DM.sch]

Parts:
I2C: M04PTH; 1X04
IC1, IC2: 74HC595N; DIL16
LED1: LED/0805; CHIP-LED0805
R1: RESISTOR0805-RES; 0805
R2, R3: 10K; 0805
S1, S2: PB_SMTFITTING; PB_SMT_TIGHT
U1: ARDUINOR3-NOIOREF-NOTEXT; ARDUINOR3-NOTEXT-NOIOREF
U$1: 8X8DM_2088AS

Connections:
3V: U1.3V
5V: I2C.2, IC1.10 (SCL), IC1.16 (VCC), IC2.10 (SCL), IC2.16 (VCC), R2.2, R3.2, U1.5V
CLK: IC1.11 (SCK), IC2.11 (SCK), U1.D8
D_IN: IC2.9 (QH*)
D_OUT: IC1.14 (SER), U1.D9
GND: I2C.1, IC1.8 (GND), IC1.13 (G), IC2.8 (GND), IC2.13 (G), LED1.C, S1.P$4 (2), S2.P$4 (2), U1.GND, U1.GND1, U1.GND2
LTH: IC1.12 (RCK), IC2.12 (RCK), U1.D7
unnamed: IC1.1 (QB), U$1.14 (R2)
unnamed: IC1.2 (QC), U$1.8 (R3)
unnamed: IC1.3 (QD), U$1.12 (R4)
unnamed: IC1.4 (QE), U$1.1 (R5)
unnamed: IC1.5 (QF), U$1.7 (R6)
unnamed: IC1.6 (QG), U$1.2 (R7)
unnamed: IC1.7 (QH), U$1.5 (R8)
unnamed: IC1.15 (QA), U$1.9 (R1)
unnamed: IC2.1 (QB), U$1.3 (C2)
unnamed: IC2.2 (QC), U$1.4 (C3)
unnamed: IC2.3 (QD), U$1.10 (C4)
unnamed: IC2.4 (QE), U$1.6 (C5)
unnamed: IC2.5 (QF), U$1.11 (C6)
unnamed: IC2.6 (QG), U$1.15 (C7)
unnamed: IC2.7 (QH), U$1.16 (C8)
unnamed: IC2.15 (QA), U$1.13 (C1)
unnamed: IC1.9 (QH*), IC2.14 (SER)
unnamed: R1.2, U1.D10
unnamed: LED1.A, R1.1
PB1: R2.1, S1.P$3 (1), U1.D5
PB2: R3.1, S2.P$3 (1), U1.D6
SCL: I2C.4, U1.A5 (A5/SCL)
SDA: I2C.3, U1.A4 (A4/SDA)
V+: U1.VIN

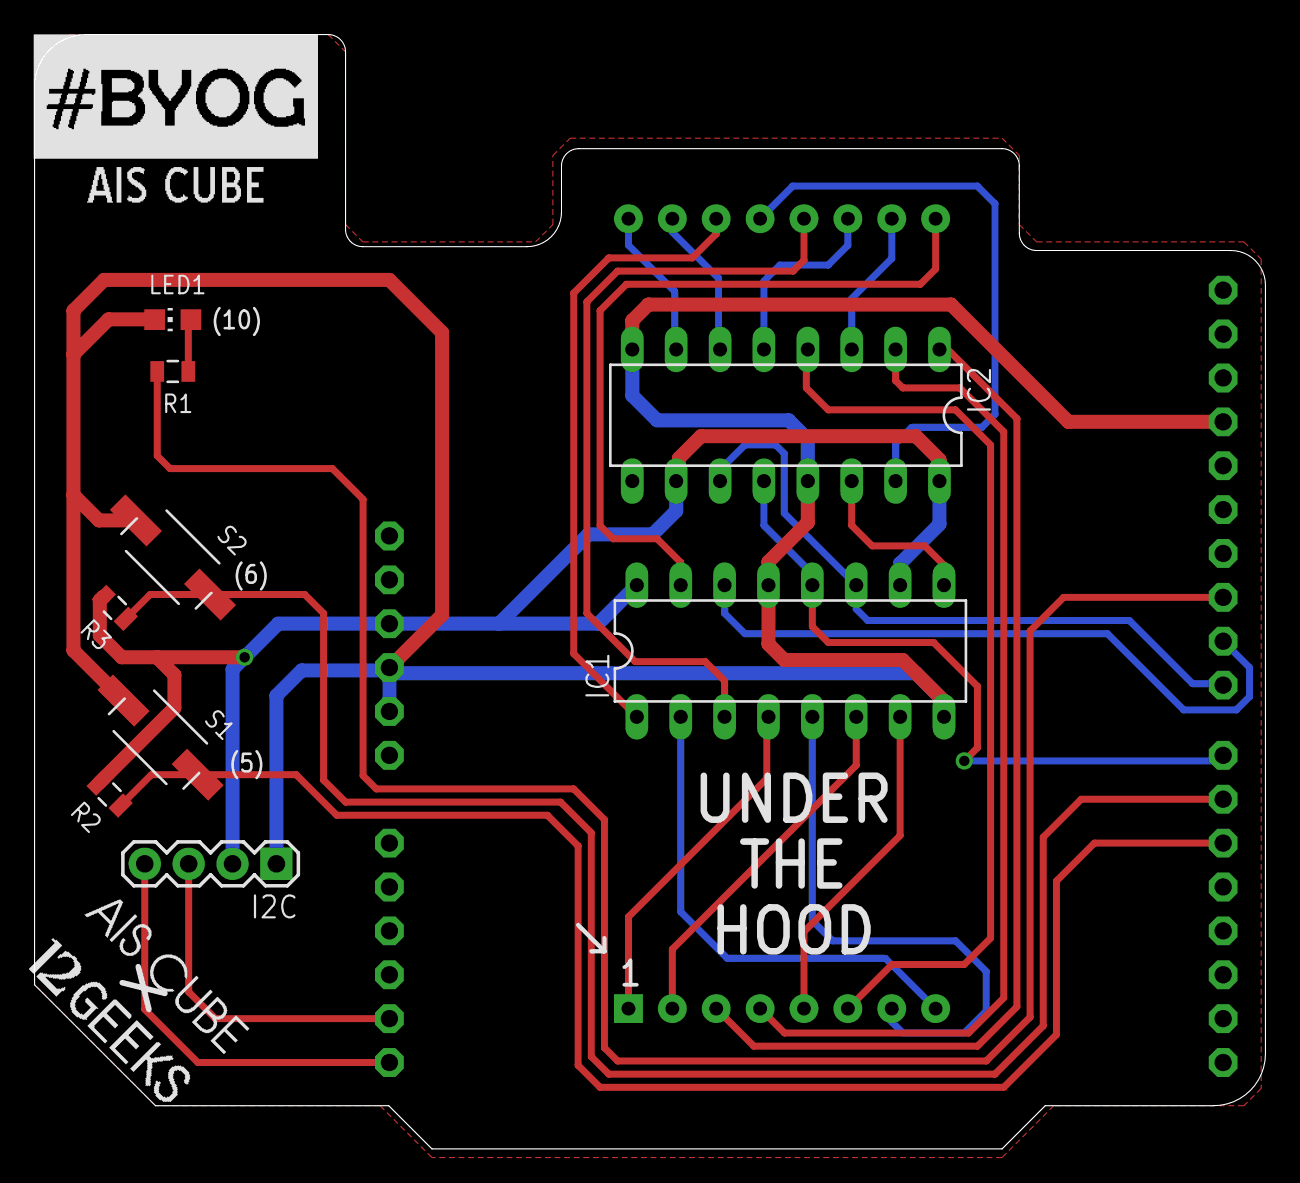
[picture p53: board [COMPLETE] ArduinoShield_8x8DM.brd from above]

Board: 2 copper layers, 71.2 x 64.5 mm, 14 parts (0 on the bottom side), 28 nets.

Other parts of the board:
U$2: LOGO_17MM
U$8: LOGO_12GEEKS
U$9: AISCUBE_LOGO_S

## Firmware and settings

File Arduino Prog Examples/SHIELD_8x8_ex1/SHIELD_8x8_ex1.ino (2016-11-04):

#include "TimerOne-master\TimerOne.h"
#include "S8x8_Lib.h"
#include "Animate.h"

int num = '1';
//===============================================================================================================================
void setup() {
  S8x8Setup();
  Serial.begin(9600);

  DisplayChar(num);
}
//===============================================================================================================================
void loop() {
  
}
//===============================================================================================================================

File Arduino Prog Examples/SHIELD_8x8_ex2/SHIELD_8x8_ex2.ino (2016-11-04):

#include "TimerOne-master\TimerOne.h"
#include "S8x8_Lib.h"
#include "Animate.h"

int num = '0';
//===============================================================================================================================
void setup() {
  S8x8Setup();
  Serial.begin(9600);

  DisplayChar(num);
}
//===============================================================================================================================
void loop() {
  for(int c=0;c<10;c++) {    
    DisplayChar(num + c);
    delay(500);
  }   
}
//===============================================================================================================================

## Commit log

2016-11-04 Session 1 Resources Added
    Added Arduino Program Examples & Notes for Session 1 of the Build Your
    Own Arduino Shield - PCB workshop organised by 12Geeks & AISCube
2016-11-11 Added in Slides & EAGLE files for Session 2
    [BYOG_Shield.brd, BYOG_Shield.sch]
2016-11-13 COMPLETE & EXPRESS versions of PCB files added
    Added in EXPRESS and COMPLETE version of the EAGLE files to
    complete/refer to.
    Use EXPRESS to jumpstart the routing task. Good luck and have fun!
    [BYOG_Shield.brd, BYOG_Shield.sch, [COMPLETE] ArduinoShield_8x8DM.brd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]
